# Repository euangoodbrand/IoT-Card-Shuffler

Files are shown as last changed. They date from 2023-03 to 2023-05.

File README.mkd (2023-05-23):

# Card Shuffler

<div style="text-align: center;">
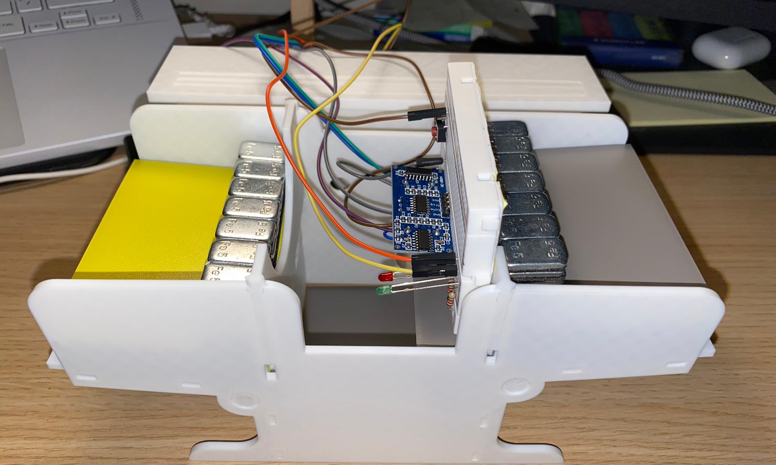
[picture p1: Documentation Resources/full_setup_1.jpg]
full_setup_1
  
</div>

This is the documentation for a Card Shuffler device, which is controlled over Wi-Fi using an aREST interface and has built-in jamming detection.

## Video Demonstration

Link: https://vimeo.com/829240523

Video below, click on image if video doesn't run (will redirect to vimeo where video is hosted)

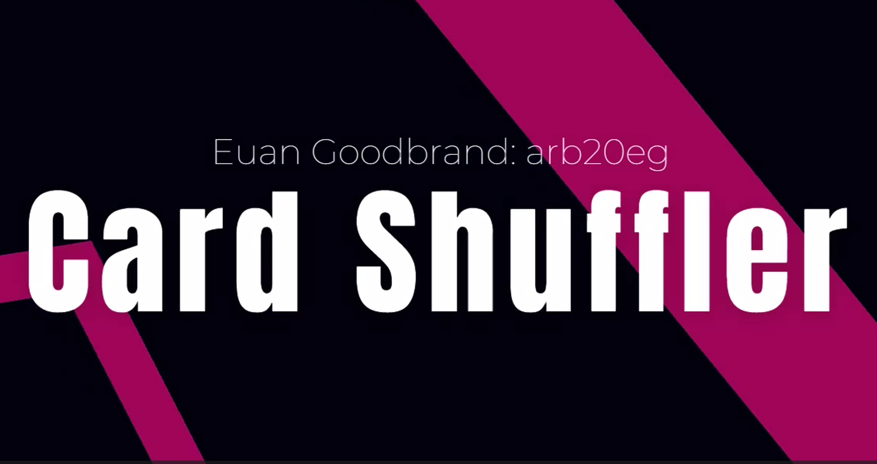
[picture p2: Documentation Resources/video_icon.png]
Video of Card Shuffler (https://vimeo.com/829240523)


## Software Design
The software is composed of two components, the aREST Interface and the Arduino code.

### aREST Interface Design
<div style="text-align: center;">
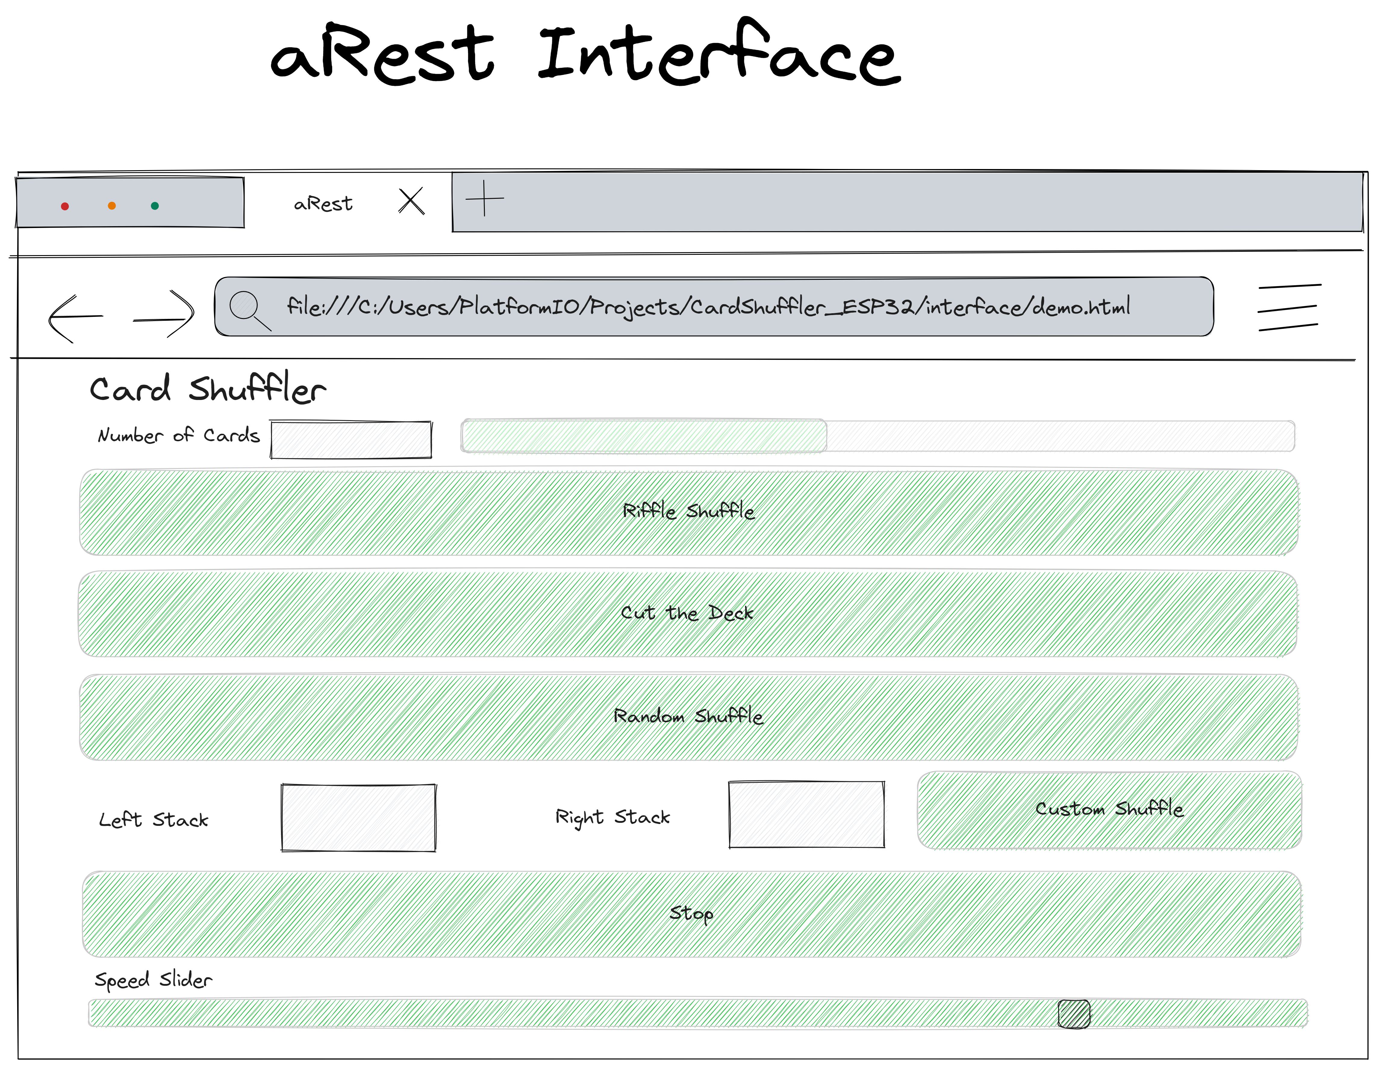
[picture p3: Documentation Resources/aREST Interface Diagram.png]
aREST Interface Design
  
</div>

The aREST interface must be easy to use and intuitive giving visual feedback to the user also. The design must also be simple and only include necessary features, no superfluous features should be on the interface and any features added should have a minimal design that is accessible. The interface was designed to have these features: Buttons for each shuffle (Riffle, Cut, Random and Custom) as well as a stop button. The user should have control over the device therefore, the user can choose the number of cards they wish to shuffle, control the speed of the shuffling via a slider and customise their own shuffle (custom shuffle). The slider was used to that the user doesn’t' enter a value outside of the motors capacity.

### Arduino code
<div style="text-align: center;">
  Software diagram
</div>
The code must be able to interact with the aREST interface as well as perform certain functions. As this is an IoT device it must firstly Connect to Wi-Fi via networking and be able to perform OTA firmware updates.
The code must also be able to control the  motors in the necessary ways to shuffle a Riffle-Shuffle, Cutting a deck, Random Shuffle and a Custom Shuffle whilst also taking into account the users selected number of cards and shuffling speed in any calculations.
The device also has an ultrasonic sensor, the code must stop all the motors whenever a distance below a certain threshold is detected which would be a card jam, the motors need to stop to ensure  no card damage is caused. Any necessary information should also be printed to the serial monitor or given to the user on the aREST interface. The code must also  incorporate a button to start Firmware updates and LEDs to inform the user of card jams detected.

## Hardware Design

The following components were used in the hardware design of the card shuffler project:

- Adafruit ESP32 Featherboard: The main microcontroller for this project, running the main logic and controlling the other hardware components. It's a powerful board with built-in Wi-Fi capabilities.

- Adafruit Motor Shield: This is used to control the DC motors which power the card shuffling mechanism. (Motor setup instructions were found here: https://gitlab.com/hamishcunningham/the-internet-of-things/-/blob/master/micasa/08-a-robocar.mkd)

- DC Motors: Two DC motors are used, which are controlled by the Motor Shield. These are responsible for the actual shuffling operation.

- Ultrasonic Sensor: An ultrasonic sensor is used to detect jams and stop the shuffler in case of issues.

- LEDs: Two LEDs are used to visually indicate the system status.

- Breadboard: Used for prototyping and connecting the various components.

These components are connected together along with the 3D printed chassis as shown in the relevant images in the connections section

### Hardware Connections

The following hardware connections are required for the code:

// HC-SR04 Sensor declarations
#define trigPin 17  // connected to A2_I34
#define echoPin 16  // connected to A1_DAC1
#define led 10      // some GPIO pin for LED1
#define led2 6      // some GPIO pin for LED2

// Create the motor shield object with the default I2C address
Adafruit_MotorShield AFMS = Adafruit_MotorShield(); 

// And connect 2 DC motors to port M3 & M4 !
Adafruit_DCMotor *L_MOTOR = AFMS.getMotor(4);
Adafruit_DCMotor *R_MOTOR = AFMS.getMotor(3);

Please make the following connections:

- Connect the `trigPin` of the HC-SR04 ultrasonic sensor to digital pin 17 of the microcontroller.
- Connect the `echoPin` of the HC-SR04 ultrasonic sensor to digital pin 16 of the microcontroller.
- Connect the `LED1` pin to digital pin 10 of the microcontroller.
- Connect the `LED2` pin to digital pin 6 of the microcontroller.

Additionally, the code utilizes the Adafruit Motor Shield library to control DC motors. Connect two DC motors to ports M3 and M4 of the Adafruit Motor Shield.

Note: Ensure that the motor shield is properly connected to the microcontroller and the necessary libraries are installed.

Finally, please refer to the hardware documentation or pinout diagrams of your specific microcontroller board and ensure the correct pin mappings for the `trigPin`, `echoPin`, `LED1`, and `LED2` connections.

**ESP32 and MotorDriver**

The ESP32 is connected to the Motordriver and the Motors in the following configuration. The setup also requires two batteries, abattery to power the motors and a lithium battery to allow the card shuffler to work without being plugged in.

<div style="text-align: center;">
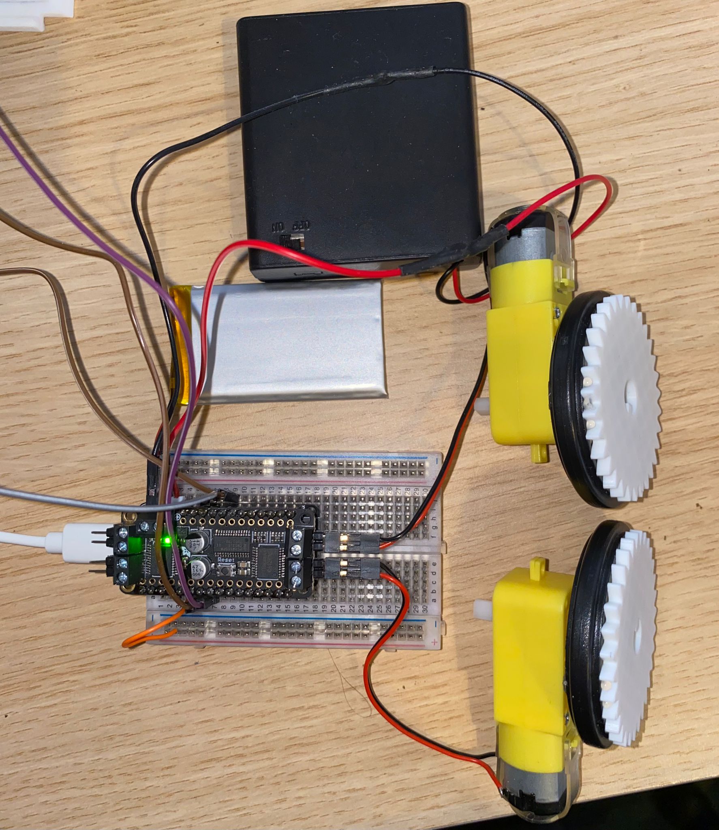
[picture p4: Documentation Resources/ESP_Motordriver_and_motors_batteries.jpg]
ESP_Motordriver_and_motors_batteries
  
</div>

**Ultrasonic Sensor**

The ultrasonic sensor is attatched to a seperate breadboard so that it can be mounted inside the chassis, this is to allow the ultrasonic sensor to be able to detect card james as well as give the user visuals of the LEDs attatched to that same breadboard. The button for OTA updates is also on this breadboard to allow the user to be able to press it easily for new firmware.

<div style="text-align: center;">
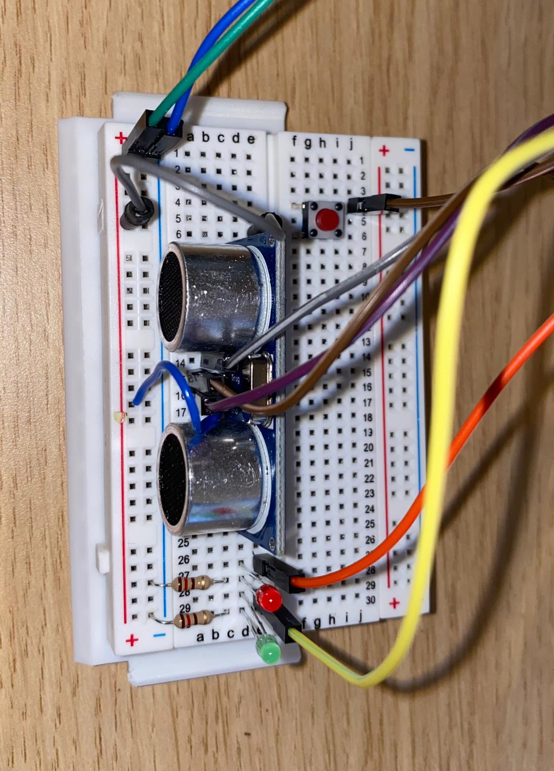
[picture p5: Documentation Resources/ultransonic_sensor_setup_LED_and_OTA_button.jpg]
ultransonic_sensor_setup_LED_and_OTA_button
  
</div>

The ultrasonic sensor breaboard can be easily mounted to the chassis using the sticky bottom of the breadboard as shown below:
<div style="text-align: center;">
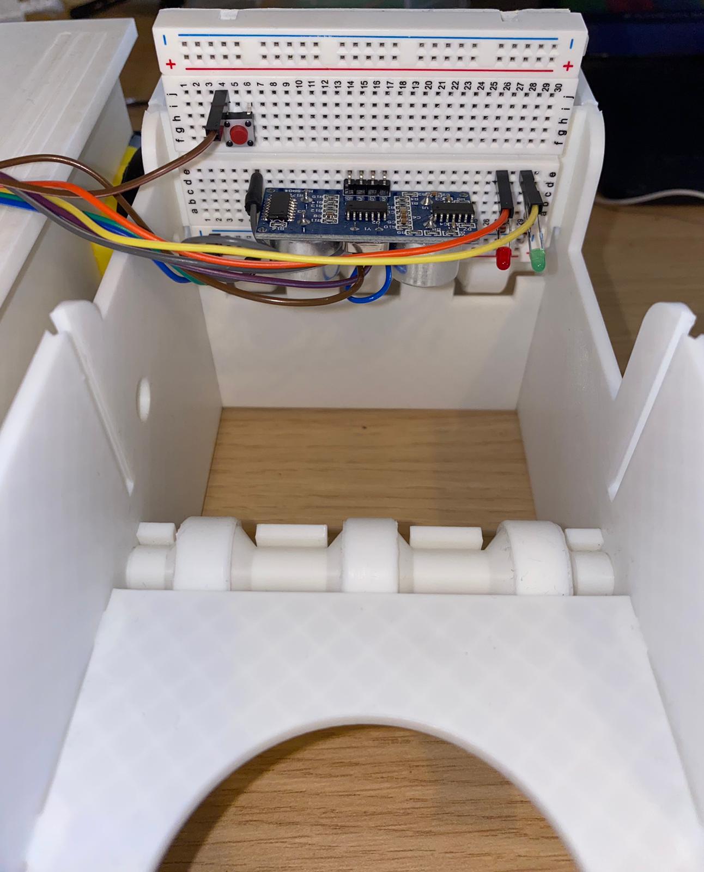
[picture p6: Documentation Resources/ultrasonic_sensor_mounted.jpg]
ultrasonic_sensor_mounted
  
</div>

## 3D Printed Chassis

The main structure of the card shuffler is a 3D printed chassis, designed to hold the cards and incorporate the mechanical parts needed for shuffling. The design should be simplistic and immediately obvious to the user how it functions such as where to put the cards. 

### Chassis Design
The components were designed using Fusion 360 software and printed using a P1P Bambu Labs 3D printer using Bambu Studio Slicer Software. All components were designed using measurements from a digital vernier callipers so that they have a high resolution of +- 0.05 mm. The 3D printer has a resolution of 0.1mm vertically and 0.4mm horizontally.

The design is made up of 15 different components:

**Sides**
The sides are the main component holding the design together, they allow the other components to connect in a secure way and hole the cards in from their sides. They include holes for the shaft to spin inside. These were printed on a smooth 3D printing bed so that the inside wall of the sides is smooth allowing the lowest friction for the cards.
<div style="text-align: center;">
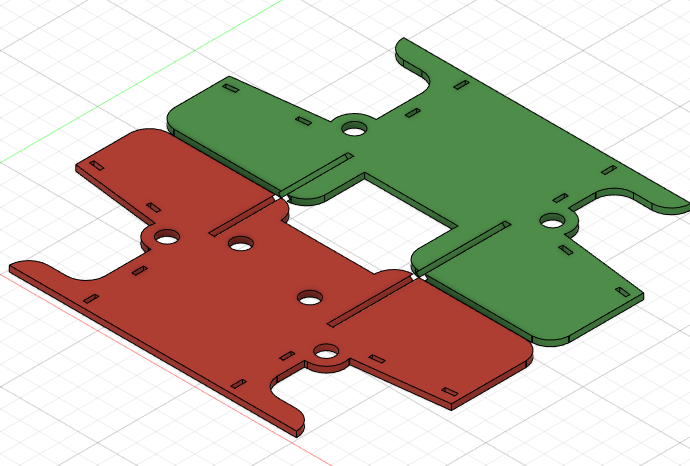
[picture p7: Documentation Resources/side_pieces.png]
side_pieces
  
</div>

**Spacers**
The spacers create horizontal structure in the shuffler and dictate the width of the cards put into the chassis. The current design allows for cards of 91 mm * 73mm and other similar smaller sized cards. Too small cards will not work. Two different designs of spacers were created for the two different shaft variants.
<div style="text-align: center;">
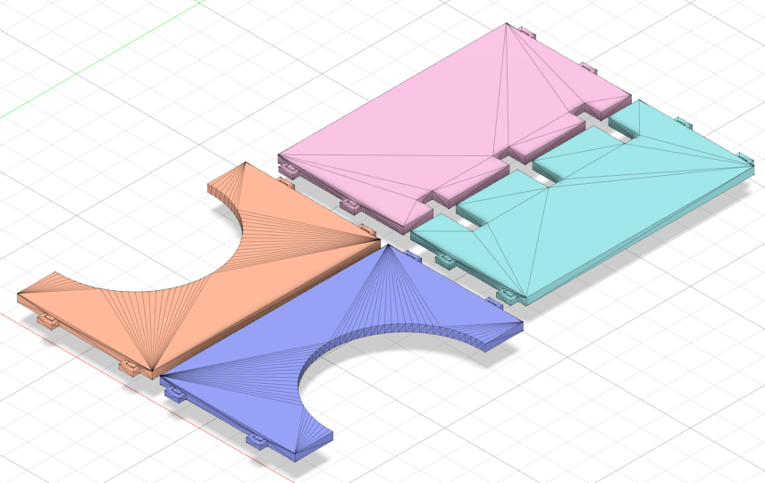
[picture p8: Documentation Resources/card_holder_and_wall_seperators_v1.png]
card_holder_and_wall_seperators_v1
  
</div>

**Card holders**
The card holders allow the cards to sit on top of them and slide off onto the motor shafts. They have a section removed to allow the easy removal and placing of cards as you are holding them. These pieces were also printed on a smooth 3D printing bed ass they make the most contact with the cards, this is to reduce friction. 
<div style="text-align: center;">
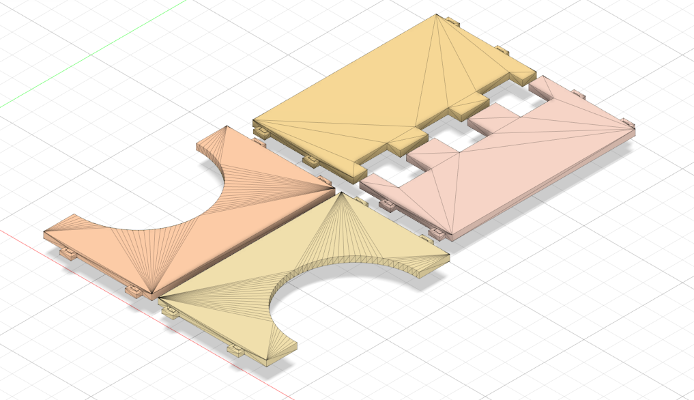
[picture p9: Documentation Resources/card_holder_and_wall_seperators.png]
card_holder_and_wall_seperators
  
</div>

**Card Blockers**
The card blocks are designs to be able to slide vertically on the side pieces, this allows the careful calibration of the blockers to only allow one card to be shuffler each time by the motors. Depending on the card thickness they ca be adjusted accordingly, this is useful for cases such as mine where I have cards in sleeves and sometimes even double sleeves that are of different thicknesses.
<div style="text-align: center;">
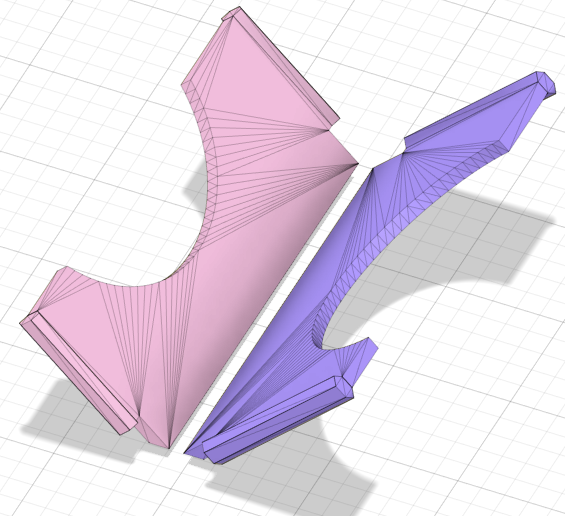
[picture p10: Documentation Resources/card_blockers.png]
card_blockers
  
</div>

**Motor Shaft**
There are two motor shaft designs v1 was found to be less effective than v2, both designs require the addition of rubber grips and are designed to hold specific rubber pieces, this is to ensure that the cards are pushed along by the motors as the plastic 3D printed is not enough to push the cards through. 

<div style="display: flex; justify-content: center;">
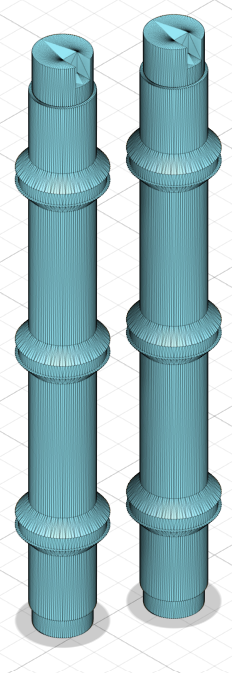
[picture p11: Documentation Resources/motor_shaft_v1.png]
motor_shaft_v1
  
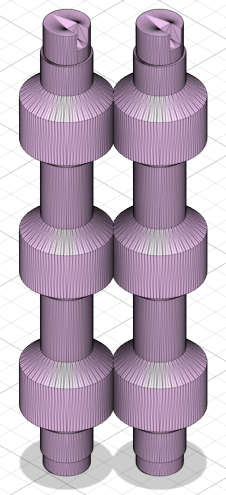
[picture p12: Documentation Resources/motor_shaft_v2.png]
motor_shaft_v2
  
</div>

The rubber bands are glued around the shaft like this:
<div style="text-align: center;">
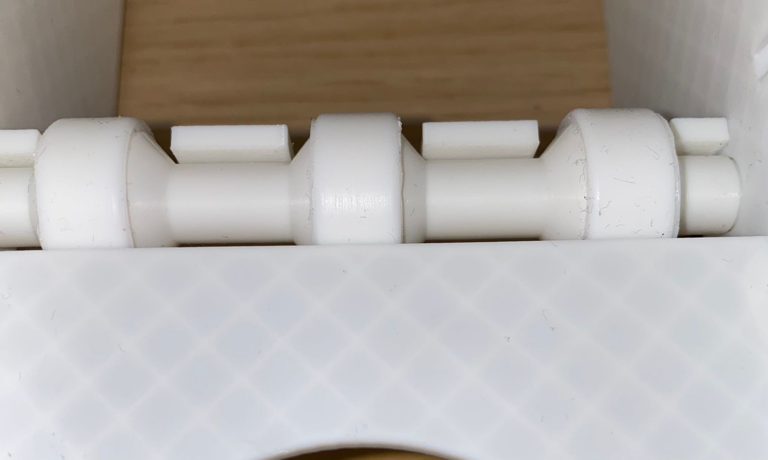
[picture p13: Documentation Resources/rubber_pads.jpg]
  
</div>

**Motor Holders**
These pieces are designed to house the motors securely, this is so that only the rotation force is applied to the shafts and not the motors or chassis themselves. This ensures the secure and steady rotation of the motors and allows the motors to run at full speed despite the wight of the cards and the top weights. This component is designed to use the small piece sticking out of the motors to securely fasten it inside.

<div style="text-align: center;">
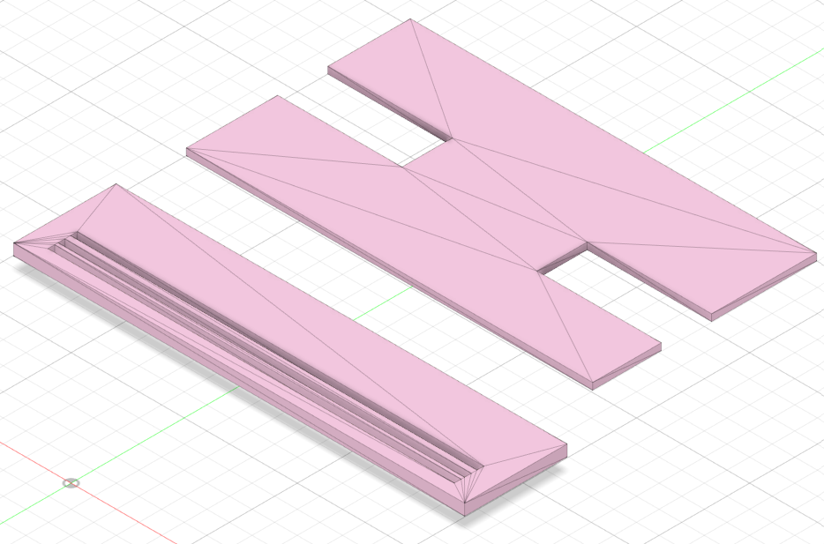
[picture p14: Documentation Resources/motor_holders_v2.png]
motor_holders_v2
  
</div>

### Assembly

The 3D Chassis is split into two main parts. The card shuffler and the Motor housing which are then connected via the gears. 

**Card Shuffler**

The card shuffler is made of 10 different 3D printed parts and is assembled like this:
<div style="text-align: center;">
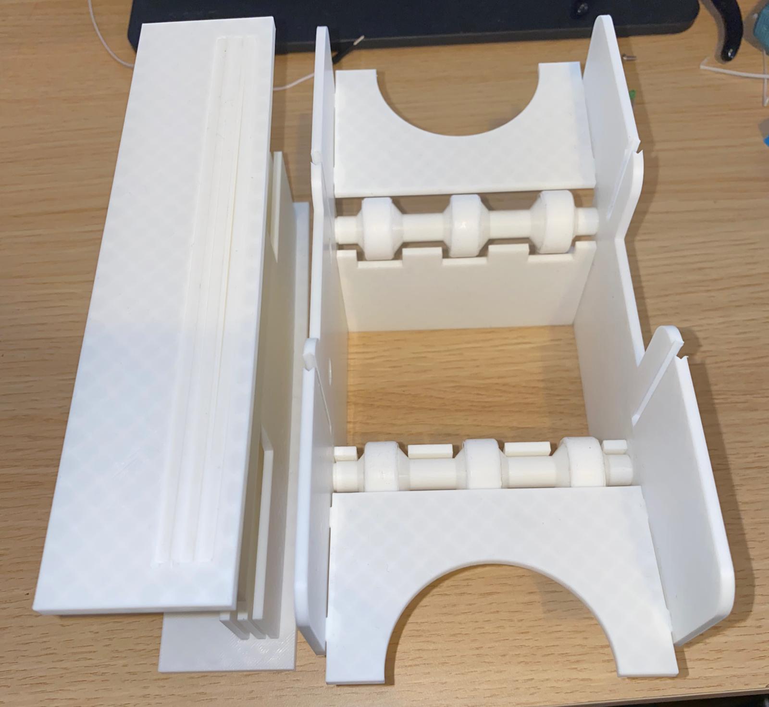
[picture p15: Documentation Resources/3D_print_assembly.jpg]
  
</div>

**Motor Housing**

The motor housing is composed of 4four 3D printed parts that are put together as so, there is a front and back to show how the motors are housed and how the gears are positioned on the front:

<div style="display: flex; justify-content: center;">
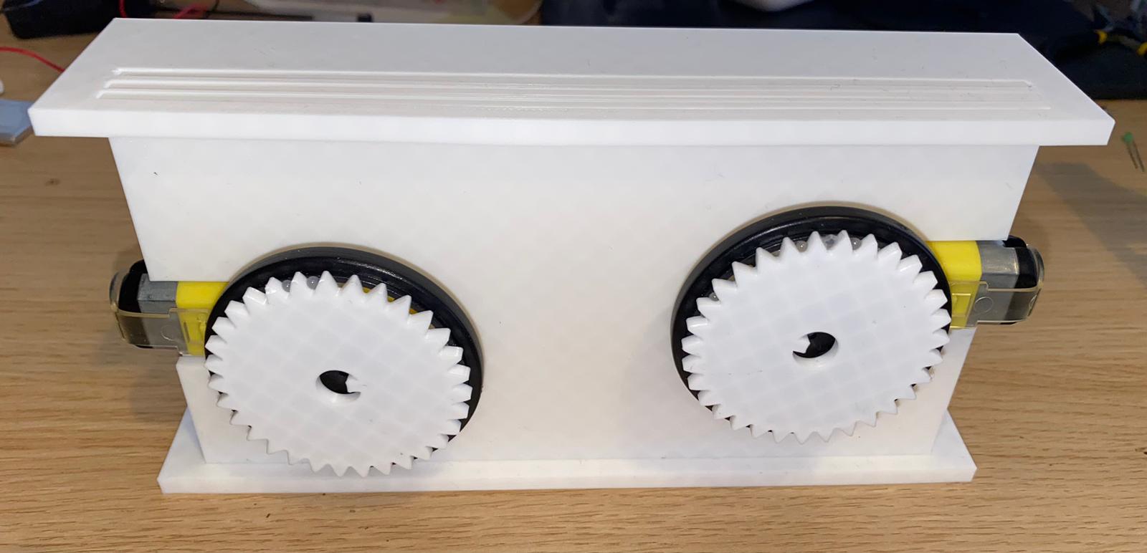
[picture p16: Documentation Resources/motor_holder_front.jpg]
MH Front
  
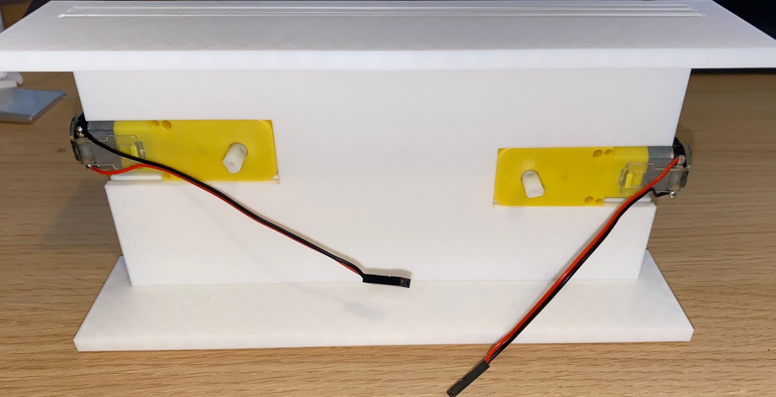
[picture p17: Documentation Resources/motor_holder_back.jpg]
MH back
  
</div>

## Libraries Used

This project uses several libraries to manage different aspects of the device's functionality. Here's a list of these libraries and their roles:

- `WiFi.h`: This library is used for managing Wi-Fi connections, allowing the device to connect to the internet. [More Information](https://github.com/espressif/arduino-esp32/tree/master/libraries/WiFi)

- `aREST.h`: This library is used for handling RESTful services, providing a simple way to interact with the device over HTTP. [More Information](https://github.com/marcoschwartz/aREST)

- `Wire.h`: This library is used for managing I2C communications, which are used for communicating with the motor shield. [More Information](https://www.arduino.cc/en/Reference/Wire)

- `Adafruit_MotorShield.h`: This library is used for controlling the Adafruit MotorShield, which is used for controlling the motors. [More Information](https://learn.adafruit.com/adafruit-motor-shield-v2-for-arduino/install-software)

- `HTTPClient.h`: This library is used for making HTTP requests. It's used in this project to check for and download firmware updates. [More Information](https://github.com/espressif/arduino-esp32/tree/master/libraries/HTTPClient)

- `Update.h`: This library is used for performing OTA updates. It's used to apply the firmware updates downloaded by HTTPClient. [More Information](https://github.com/espressif/arduino-esp32/tree/master/libraries/Update)

## Hardware requirements
- ESP32 Featherboard or other WiFi-enabled microcontroller
- Adafruit MotorShield Board
- HC-SR04 ultrasonic sensor
- Two DC motors
- Two LEDs (for jamming indication)
- Button for OTA Updates
- 3D Printed Case (Stl files can be found in Hardware Design Folder)
- Some cards to shuffle :) (specifically 93mm * 71mm)
- Jumper cables
- Rubber grips for the motor shafts
- Small weights for holding the cards flat

## Software
### Requirements
- Arduino IDE (or any compatible environment, e.g. vscode with platformio)
- Necessary libraries installed

**List of Libraries**
- [WiFi](https://www.arduino.cc/en/Reference/WiFi)
- [aREST by marcoschwartz](https://www.arduino.cc/reference/en/libraries/arest/)
- [Wire](https://www.arduino.cc/en/Reference/Wire)
- [Adafruit Motor Shield V2 Library by adafruit](https://www.arduino.cc/reference/en/libraries/adafruit-motor-shield-v2-library/)
- [Adafruit SPIFlash by adafruit](https://www.arduino.cc/reference/en/libraries/adafruit-spiflash/)
- [AsyncTCP by me-no-dev](https://github.com/me-no-dev/AsyncTCP)
- [ESP Async WebServer by me-no-dev](https://github.com/me-no-dev/ESPAsyncWebServer)
- [Adafruit BusIO](https://www.arduino.cc/reference/en/libraries/adafruit-busio/)
- [SPI](https://www.arduino.cc/en/Reference/SPI)
- [Adafruit ImageReader Library](https://www.arduino.cc/reference/en/libraries/adafruit-imagereader-library/)
- [Adafruit Unified Sensor](https://www.arduino.cc/reference/en/libraries/adafruit-unified-sensor/)
- [DNSServer](https://www.arduino.cc/en/Reference/DNSServer)
- [ESPmDNS](https://www.arduino.cc/en/Reference/ESPmDNS)
- [FS](https://www.arduino.cc/en/Reference/FS)
- [HTTPClient](https://www.arduino.cc/en/Reference/HTTPClient)
- [arduino-lmic by hamishcunningham](https://github.com/hamishcunningham/arduino-lmic)
- [Preferences](https://www.arduino.cc/en/Reference/Preferences)
- [Update](https://www.arduino.cc/en/Reference/Update)
- [WebServer](https://www.arduino.cc/en/Reference/WebServer)
- [WiFiClientSecure](https://www.arduino.cc/en/Reference/WiFiClientSecure)

### Constants
The following constants are defined, use them wisely:
-  `FIRMWARE_VERSION`: Current firmware version of the device.
-  `FIRMWARE_SERVER_IP_ADDR`: IP address of the firmware server.
-  `FIRMWARE_SERVER_PORT`: Port number of the firmware server.
-  `apSSID`: SSID for the ESP32's access point.
-  `apPassword`: Password for the ESP32's access point (and no, "password123" is not a good choice ~~ignore my password~~).

## Setup and Usage
- You can control the motors by sending requests to the following REST endpoints:
  - `/stop`
  - `/oppositeConstant`
  - `/alternating`
  - `/randomMotion`
  - `/customSuhffle`
  - The device uses an ultrasonic sensor to detect card jams. If a jam is detected, it stops the motors and turns on the red LED.

## Provisioning Instructions:
<div>
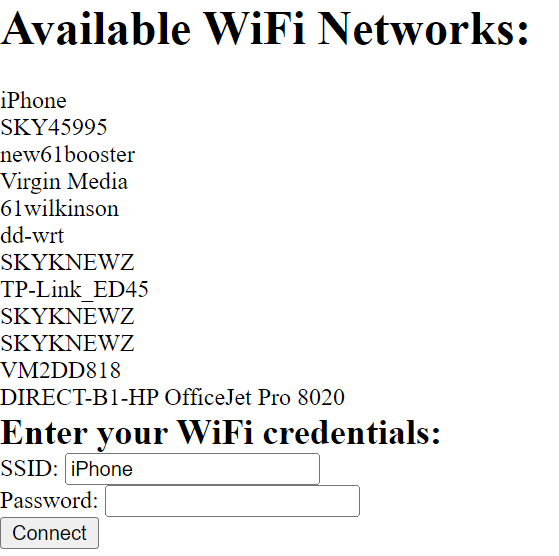
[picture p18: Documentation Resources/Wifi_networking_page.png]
Wifi_networking_page
  
</div>

The Card Shuffler also has provisioning capability allowing connection to any Wifi and easy setup.

These instructions will guide you through the process of provisioning your ESP device, so that it can connect to your Wi-Fi network and become accessible via its own access point.
1.  **Put the ESP into bootloader mode:**
 - Hold down the "boot" button on the ESP board, then press the "reset" button.
 - Release the "reset" button, then release the "boot" button.
2.  **Burn the code onto the ESP:**
 - Use your preferred method to burn the code onto the ESP board.
3.  **Connect to your computer and select the relevant port:**
 - Connect your ESP board to your computer via USB.
 - Select the relevant port in your programming software.
 - Press the "reset" button to run the code.
4.  **Connect to the access point created by the ESP:**
 - The ESP will create its own access point, which you can connect to.
 - Define a name and password for the access point.
5.  **View the website from the ESP:**
 - In a web browser, go to the URL http://192.168.4.1 to view the website hosted by the ESP.
6.  **Enter your Wi-Fi credentials:**
 - Type in the Wi-Fi credentials that you want the ESP to connect to.
 - Make sure that your firewall is not blocking this connection.

## OTA Update and Instructions:
- The code includes an Over-The-Air (OTA) update mechanism. The device checks for updates from a specified server at startup and applies them if found.

These instructions will guide you through the process of updating your ESP device over the air (OTA), using a Python server and compiled binary files.
1.  **Ensure that your computer and ESP are on the same Wi-Fi network:**
 - Connect your computer and ESP to the same Wi-Fi network.
 - You can use a hotspot if you prefer.
2.  **Find the IPv4 address of your computer's wireless LAN:**
 - Open a new terminal and type "ipconfig".
 - Look for the IPv4 address under the "Wireless LAN" section.
3.  **Start a Python server:**
 - Open another terminal window and type "python -m http.server 8000".
 - This will start a server that listens on port 8000.
4.  **Upload the sketch.ino file:**
 - Use your preferred method to upload the sketch.ino file to your ESP board.
5.  **Increment the firmware version:**
 - Go to "Sketch" > "Export compiled binary" in your programming software.
 - Save the binary file as "N.bin", where "N" is the version number you are updating to.
 - Increment the version number in your sketch.
6.  **Save the binary file to the Python server directory:**
 - Save the binary file to the directory where you ran the Python server (step 3).
 - Save it as "N.bin", where "N" is the version number you are updating to.
7.  **Add a version.txt file:**
 - Create a file called "version.txt" in the same directory as the binary file.
 - Inside the file, add the integer version number that you are updating to.
8.  **Reset the ESP board and open the serial monitor:**
 - Reset the ESP board by pressing the "reset" button.
 - Open the serial monitor in your programming software and select the correct port.
9.  **Wait for the update to complete:**
 - Press the button on the breadboard to start the updating process.
 - The ESP board will connect to the Python server and download the new firmware.
 - Wait for the update to complete.

## Testing

### Sensor Testing
The sensor was tested at various distances measured with a calliper and these expected distances were compared to the actual read distances from the sensor, this showed that the sensor outputted results to the nearest cm. This changed the design direction as originally I has intended to use the ultrasonic sensor for both detecting card jams and measuring the height if the stack of cards to determine when to stop shuffling when enough cards were in the stack, however as cards are much thinner than 1cm this couldn't be done. In the end only card jamming detection could be done with the hardware at the resolution.

<div style="text-align: center;">
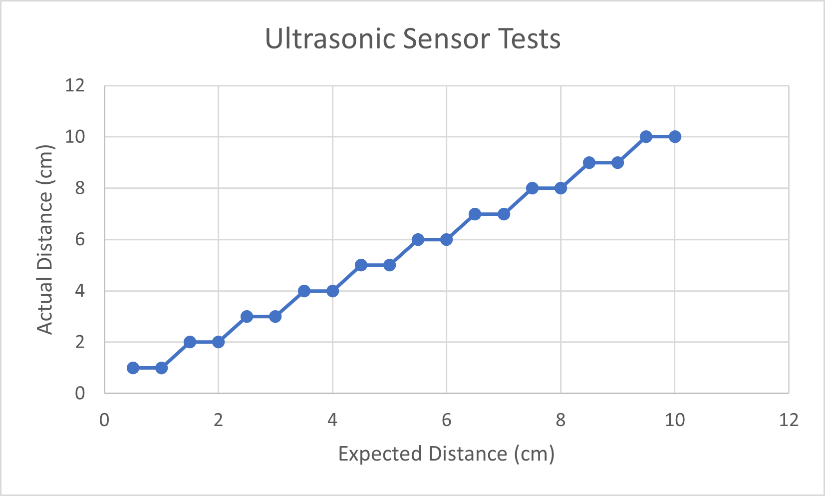
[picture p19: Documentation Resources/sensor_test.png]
sensor_test
  
</div>

### Motor Timing Testing for number of Cards Shuffled
Testing and calibration was done on the  motor timings. It was found that the amount of cards being shuffled was much higher than expected to the point the motors would continue running even after the maximum amount of cards the chassis could hold had already been shuffled. This called for proper testing and calibration.
It was found that the amount of cards shuffled was around 5 times as much as expected as shown in the table above, therefore, the code was altered to reduce the motor running duration by a scale of 5. The below table is the resulting number of cards shuffled based off the number inputted and the test was done twice to confirm. This shows that the card shuffler can shuffle the correct amount of cards pretty close to the expected number, further calibration could get the accuracy correct every time but this would require a much longer calibration process to approach  the correct calibrated values which could be done in potential further work.
<div style="display: flex; justify-content: center;">
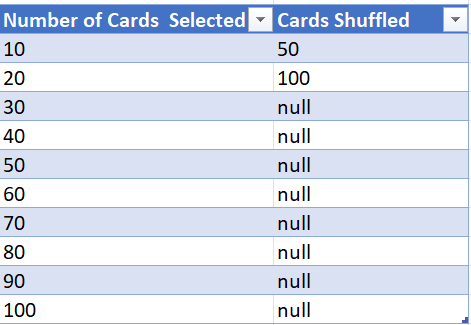
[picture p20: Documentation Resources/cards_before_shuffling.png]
cards_before_shuffling
  
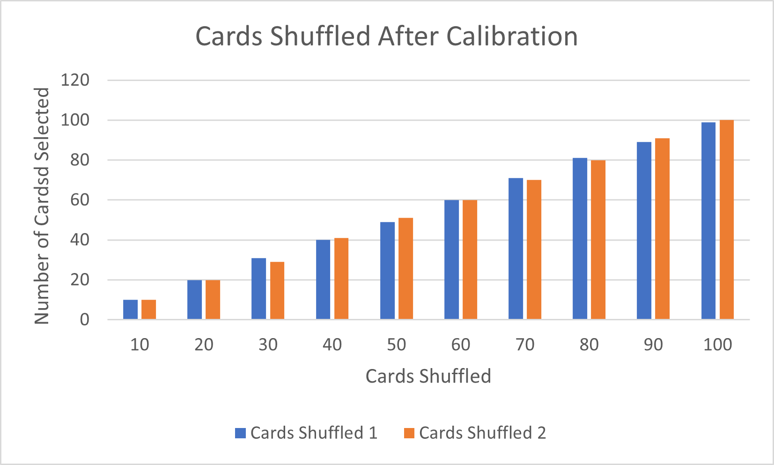
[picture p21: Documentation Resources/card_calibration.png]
card_calibration
  
</div>

### 3D Printed chassis testing and Iterative Design Process
Before the motors were added to the design or the motor holders were even designed various testing has been done to ensure the chassis could shuffle cards before going forward with the electronic or software design and implementation. 
Multiple iterations of the chassis were made and tested with slow improvements.
The first iteration was printed at too low a quality and needed to be printed again using a higher resolution, the lower quality caused connections to not fit correctly and the shafts to grind as I cranked them which proved difficult meaning that the motors wouldn’t be able to spin them. 

<div style="text-align: center;">
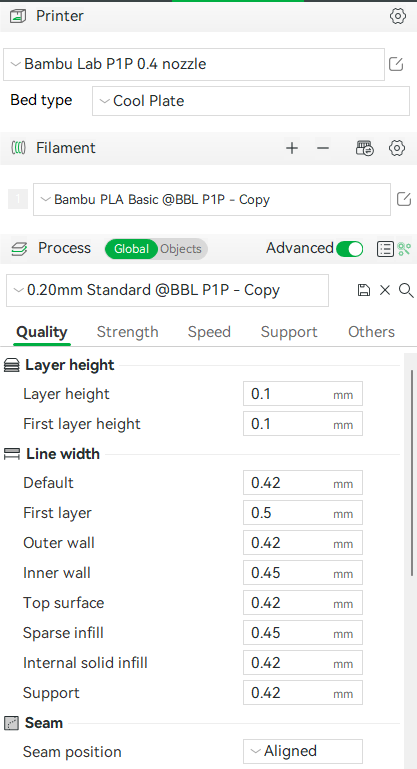
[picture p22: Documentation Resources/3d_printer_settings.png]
3d_printer_settings
  
</div>

After a reprint at 0.1mm layer height there were other issues, due to the 3D printed bed temperature being too low the PLA material warped heavily causing the chassis to not fit together correctly and not sit flat on any surfaces.
I increased the temperature of the hot bed to 55 degrees Celsius and the chassis now fit together correctly and the shafters rotated relatively smoothly, however I noticed the texture of the shafts was rougher than I expected, this was due to 3D printing the shafts horizontally and not vertically meaning the shafters were essentially made of many square cross sections rather than circular ones which is  not good for rotating parts. After reprinting these correctly the chassis worked and the shafts spun smoothly.
The process was not finished though as the cards did not make contact with the shaft by a few mm,  even adding rubber grips didn't allow the cards to touch. Therefore, I redesigned new shafts and new spacers to house them. This meant the shaft was thicker and now made contact with the cards when rubber grips were added. 
The device was now capable of shuffling but there was some holdups due to friction between the chassis and the cards. This was because the hot bed that my 3D printer came with was a textured bed meaning it applied a rough texture to all my 3D prints, this is normally good to break up the lines produced by a 3d printer but for parts requiring low friction this was an issue. 
I researched compatible smooth hot beds and purchased one, after it arrived I reprinted the parts that made contact with the cards or shafts and had these areas face down on the printer bed so they adopted the smooth face, this also meant I had to buy a flat tool to help remove them as no texture made the 3D prints adhere to the bed.
Finally, the last problem was the cards bending. Not all cards were able to stay perfectly flat and therefore, would not go under the card blocker and through the slot. This meant that weights like the ones in the image below were needed to apply constant downwards pressure. This also helped by adding extra downforce getting extra grip with the rubber.
After this the cards printed very well and smoothly and the chassis design was complete.

<div style="text-align: center;">
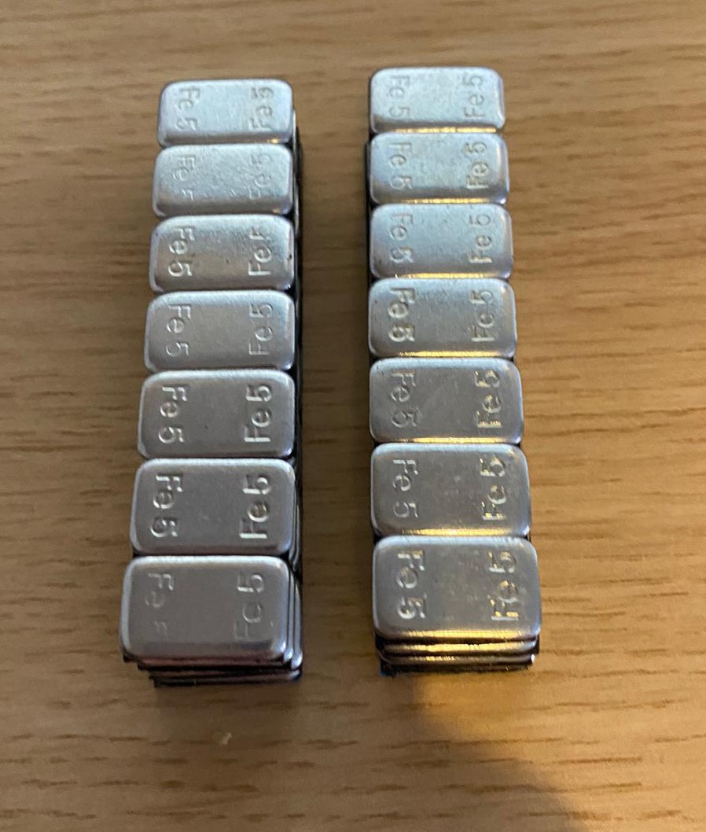
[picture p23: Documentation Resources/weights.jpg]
  
</div>

### Unit Testing Arduino Code
Unit testing was attempted but there are no standard built-in unit testing frameworks in C++ for Arduino (like JUnit for Java or unittest for Python). This code does not lend itself easily to unit testing, as it's largely dependent on hardware interactions and also on the aREST library. Also, the code would need to be largely refactored to allow for unit testing by abstracting the functions which would require  larger time frame than the project allows, and it would likely not be worth it due to most of the testing being reliant on hardware which unit tests cannot account for.

### Acceptance Testing
Acceptance testing seems to be the most appropriate type of testing for this project given the different components and the time allowed. 

**Acceptance Criteria:**
- The different shuffles must shuffle as expected.
- The card counter should output the expected number of cards.
- The progress bar should start when the cards start shuffling and finish at the same time the shuffling is over.
- The card counter should always show the correct value for cards shuffled.
- The ultrasonic sensor should correctly identify card jams.
- The cards should not be damaged.
- The user should be able to select the number of cards to shuffle.
- The user should be able to select the speed of the shuffler.
- The interface feedback (progress bar and cad counter) should reset for each new shuffle.

The project has been tested from the perspective of the user as a whole to ensure that it meets the specifications that the user would expect. Each shuffle type has been tested with different numbers of cards and at different speeds. The results were that the shuffle types shuffled as expected, outputted the correct number of times even at different speeds and the progress bar and card counter were accurate in their timings and for the amount of cards shuffled throughout the process. the ultrasonic sensor correctly identified card jams and stops the motors as well as the stop button stopping the motors when pressed. The interface correctly resets when a new shuffle is performed.

### Overall Testing
|Test No.|Description|Expected Result|Actual Result|Successful Implementation?|
|:----|:----|:----|:----|:----|
|1|Test WiFi connectivity: Verify device can connect to WiFi network|Connection should be successful and stable|Connection was successful and stable|Yes|
|1.1|Test different WiFi networks: Verify device can connect to multiple networks with varying security protocols (WEP, WPA2, WPA3, etc.)|The device should be able to connect to all supported types of networks|Device successfully connected to all tested networks|Yes|
|1.2|Test WiFi signal strength: Verify device can connect to WiFi network from different distances|Device should maintain stable connection within the specified range|Stable connection was maintained within the specified range|Yes|
|1.3|Test WiFi auto-reconnect: Verify that the device reconnects to the network after losing connectivity|Device should reconnect after the network is restored|Device reconnected after pressing the reset button|Yes|
|2|Test OTA update functionality: Check if device can receive, process, and install updates via WiFi|Firmware update should occur without error|Firmware update was successful|Yes|
|2.1|Test OTA update integrity: Check if updates install correctly without data corruption|The update should install and the system should work as intended after the update|Update installed correctly and system worked as intended|Yes|
|2.2|Test OTA update roll-back: Verify if the device can revert to previous firmware version in case of an unsuccessful update|Device should be able to revert to previous firmware version if an update fails|Device reverted to previous firmware version after naming the old firmware as a new version|Yes|
|3|Test Ultrasonic Sensor functionality: Verify sensor can measure and report accurate distances|Correct distance should be returned|Correct distance was returned|Yes|
|4|Test Motor operation: Verify motors can run smoothly without errors|Motors should run without error|Motors ran without error|Yes|
|5|Test stop() function: Verify that both motors stop when the function is called|Both motors should stop|Both motors stopped as expected|Yes|
|6|Test oppositeConstant() function: Verify that motors can run in opposite directions when the function is called|Motors should run in opposite directions|Motors ran in opposite directions as expected|Yes|
|7|Test alternating() function: Verify that motors can run alternately when the function is called|Motors should run alternately|Motors ran alternately as expected|Yes|
|8|Test randomMotion() function: Verify that motors can run in random motions when the function is called|Motors should run in random motion|Motors ran in random motion as expected|Yes|
|9|Test customShuffle() function: Verify that cards can be shuffled in a custom manner when the function is called|Cards should be shuffled customly|Cards were shuffled in a custom manner as expected|Yes|
|10|Test the interface's connection with the device: Verify the UI can successfully interact with the device|Successful interaction with the device|Interaction with the device was successful|Yes|
|11|Test shufflingSpeed adjustment on the interface: Verify that changes made on the interface reflect in the shuffling speed|Shuffling speed should change correctly|Shuffling speed changed correctly|Yes|
|12|Test the 'oppositeConstant' button on the interface: Verify that pressing the button shuffles cards in an opposite constant manner|Cards should be shuffled in opposite constant manner|Cards were shuffled in opposite constant manner|Yes|
|13|Test the 'alternating' button on the interface: Verify that pressing the button shuffles cards in an alternating manner|Cards should be shuffled in alternating manner|Cards were shuffled in alternating manner|Yes|
|14|Test the 'randomMotion' button on the interface: Verify that pressing the button shuffles cards in a random motion|Cards should be shuffled in random motion|Cards were shuffled in random motion|Yes|
|15|Test the progress bar and card count on the interface: Verify that the UI displays the correct progress and card count|Should display progress and count correctly|Progress and count were displayed correctly|Yes|
|16|Test the OTA update notification: Verify that the device provides an alert or notification when an OTA update is available|The device should provide a timely notification when an OTA update is available|A timely notification was provided when an OTA update was available|Yes|
|17|Test Ultrasonic Sensor calibration: Verify if the sensor can be properly calibrated for accurate distance measurement|The sensor should be correctly calibrated and provide accurate distance readings|Sensor was correctly calibrated and provided accurate readings|Yes|
|18|Test if motors can resume after stop(): Verify if the motors can resume operation after the stop() function is called|Motors should resume operation without error|Motors resumed operation without error|Yes|
|19|Test the responsiveness of the interface: Verify the interface reacts promptly to user interactions|The interface should respond quickly to all user interactions|The interface responded quickly to all user interactions|Yes|
|20|Test the speed control of the motors: Verify if the speed of the motors can be controlled effectively|The speed of the motors should change correctly as per control inputs|The speed of the motors changed correctly as per control inputs|Yes|
|21|Test card counting accuracy: Verify the device correctly counts the number of cards shuffled|The device should provide a correct count of cards shuffled|The device provided a correct count of cards shuffled|Yes|
|22|Test the system's ability to handle different card types: Verify the device can handle different types of cards (e.g., plastic, paper, different sizes)|The device should be able to handle all supported card types effectively| The device could handle call standard card sizes below the size of 91mm * 71mm|Yes|

## Self-Assessment

Reflecting on this project, there are several areas where improvements can be made in future iterations and other projects.

### Workspace Environment
Maintaining a well-organized and properly equipped workspace is essential for efficiency and safety. For instance, filing parts of my 3D prints caused my mousepad to be frayed which is whatt I was building the project. This was my favourite mousepad so it's a shame, the lesson learnt is to have a proper setup when dealing with a project of this nature.

### Hardware Understanding
Greater knowledge and understanding of the hardware used in the project can lead to better design decisions and problem-solving. An instance from this project was a motor getting blown during testing. This could have been avoided with more comprehensive understanding of the motor's power requirements and operating conditions. In the future, I will look into hardware specifications further as well as their operating principles before integrating them into the design.

### Documentation
Good documentation practices are crucial not only for project management but also for troubleshooting and further development. During the course of this project, it was noticed that better documentation during the development phase, rather than close to the end, would have saved time and confusion. An example was not remembering which pin was assigned to which motor upon reassembly causing lots of wasted time. Going forward, regular updates to the documentation during the development phase will be implemented, detailing decisions, changes, and important specifications. 

### More research

More research could have gone into other similar designs that already exist. If more research was done then maybe it would have required less iterations to get to a working solution. Below is an image of the 3D parts printed that didn't end up in the final design due to different problems.

<div style="text-align: center;">
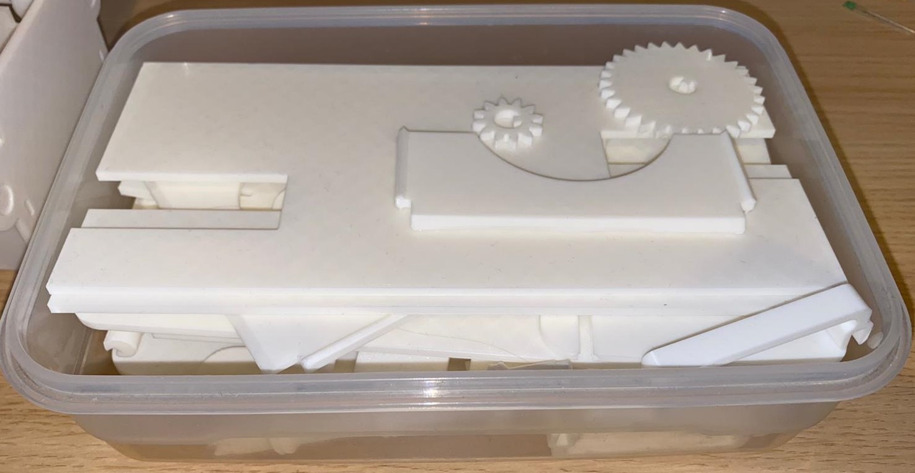
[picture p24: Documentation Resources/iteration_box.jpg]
iteration_box
  
</div>

### Future Improvements

**Adjustable Card Guide**
In future iterations of this project, implementing an adjustable card guide could be a useful feature. This mechanism, similar to the adjustable paper trays found in printers, would allow the shuffler to accommodate various sizes of cards. It would involve creating a movable guide within the card holder to securely position cards of different widths and lengths. This feature would increase the versatility of the card shuffler, allowing it to be used with a wider range of card games and deck styles.

**Improved Card Retrieval Mechanism**
Presently, accessing shuffled cards can be a bit challenging. For future iterations, an improved card retrieval mechanism could be designed. This could be a chute that guides the shuffled cards to a specific location or a platform where the shuffled cards are collected for easy pickup. 

**Enhanced Shuffling Mechanism**
The current shuffling mechanism moves the bottom card from one of two piles. While this does shuffle the cards randomly, it does not allow for all possible card permeations. Future versions could look at incorporating a more advanced shuffling algorithm or mechanism. This could include random selection of cards from different positions within the pile.

**User Interface**
The user interface of this project is simple and functional, but there is room for enhancement. Currently, the user interface only allows for changing the number of cards, shuffling speed and different shuffling methods adding the abililty to adjust settings for the card guide or other features could prove useful.

**Connectivity and IoT Security**
The current project utilizes aREST.js for network connectivity, which, while functional, presents certain limitations particularly concerning security. Future iterations would benefit from exploring alternative IoT platforms that provide enhanced security features such as AWS IoT or Google Cloud IoT.

**Smartphone Integration**
Integrating the card shuffler with a smartphone application could provide additional functionality and convenience. The smartphone app could allow users to control and monitor the shuffling process remotely, adjust settings, and receive notifications or alerts. This would enhance the user experience and provide more flexibility in using the card shuffler.

### What went well?

**Meeting Project Specifications**
Overall, the project successfully met its specifications, resulting in the creation of a functional card shuffling IoT device. The device is capable of shuffling cards, detecting card jams, and providing a user interface for control and monitoring.

**Sturdy Chassis Design**
The chassis of the device has a sturdy build and remains in excellent condition even after extensive testing. The 3D printed nature of the design allows for easy maintainability, scalability, and upgrades. Parts can be easily replaced or modified, providing flexibility for future improvements or alterations to accommodate different card sizes or design preferences.

**Functional User Interface**
The user interface of the device is simple and functional. Users can control the number of cards to shuffle, adjust the shuffling speed, and choose different shuffling methods. The implementation of REST calls and WiFi connectivity provides a convenient way to interact with the device remotely.

**Ease of Documentation Updates**
During the project, the importance of documentation became evident. Although there were some improvements to be made in the documentation process, updating the documentation as the project progressed was relatively easy due to the use of Markdown format. This allowed for clear and organized documentation, facilitating future development, troubleshooting, and sharing of the project.

**Time Management and Progress**
The project benefited from good time management practices, ensuring consistent and steady progress. The order in which tasks were completed was well-planned and logical, allowing for efficient development and troubleshooting. Regular tracking of progress and adherence to timelines helped maintain momentum and deliver the project within the expected timeframe.

**Testing and Debugging**
Thorough testing and debugging played a crucial role in the success of the project. Testing was conducted at various stages to ensure the functionality and reliability of the device. Issues and bugs were identified and addressed promptly, resulting in a stable final product. However, further improvements could be made in expanding the test coverage and implementing automated testing procedures.

**Learning and Skill Development**
The project provided valuable opportunities for learning and skill development. Through hands-on implementation, I gained practical experience in various aspects of hardware integration, software development, and IoT connectivity as well as some other skills such as using Fusion 360 and CAD design.

## Additional Resources and References

Below are some important resources and references that will provide further understanding and context to the project:

1. **Arduino Programming Language (API)**: This is the main reference to understand the Arduino Programming Language used to program the microcontroller in this project. You can find it [here](https://www.arduino.cc/reference/en/).

2. **WiFi.h**: This library provides the necessary functions to connect to Wi-Fi networks and set up an access point. Check out the source [here](https://github.com/espressif/arduino-esp32/tree/master/libraries/WiFi). Course notes on WiFI based provisioning: https://iot.unphone.net/#wifi-based-provisioning

3. **WebServer.h**: This library is used to create a simple HTTP server on the ESP32. View the source [here](https://github.com/espressif/arduino-esp32/tree/master/libraries/WebServer).

4. **HTTPClient.h**: This library provides functions to make HTTP requests, used to get firmware updates from the server. The source is available [here](https://github.com/espressif/arduino-esp32/tree/master/libraries/HTTPClient).

5. **Update.h**: This library is used for handling OTA updates on the ESP32. You can check out the source [here](https://github.com/espressif/arduino-esp32/tree/master/libraries/Update).

6. **Adafruit Motor Shield Library Documentation**: This [documentation](https://learn.adafruit.com/adafruit-motor-shield-v2-for-arduino/install-software) provides essential information about the motor shield library used in the project.

7. **Adafruit HUZZAH32 – ESP32 Feather Board**: This is the datasheet for the Adafruit HUZZAH32 – ESP32 Feather Board. It is available [here](https://learn.adafruit.com/adafruit-huzzah32-esp32-feather).

8. **aREST Library**: Here is the [aREST library](https://arest.io/) that makes building IoT devices easier.

9. **Arduino OTA Updates**: Check out this [tutorial](https://randomnerdtutorials.com/esp32-over-the-air-ota-programming/) to understand more about OTA updates in Arduino. Course notes on OTA updates: https://iot.unphone.net/#over-the-air-updates-ota

10. **Motor Setup**: https://gitlab.com/hamishcunningham/the-internet-of-things/-/blob/master/micasa/08-a-robocar.mkd  and https://iot.unphone.net/#a-simple-robot-car

11. **Ultrasonic Sensor HC-SR04 Setup Instructions** found here: https://gitlab.com/hamishcunningham/the-internet-of-things/-/blob/master/micasa/08-ultrasonicsensors.mkd and https://iot.unphone.net/#ultrasonic-sensors

12. **ESP32 S3**: Programming guide: https://docs.espressif.com/projects/esp-idf/en/latest/esp32s3/get-started/index.html and course notes: https://iot.unphone.net/#esp-idf-freertos-and-the-esp32-arduino-core

## Contact
- You can reach me at [egoodbrand1@sheffield.ac.uk](mailto:egoodbrand1@sheffield.ac.uk) for any queries.

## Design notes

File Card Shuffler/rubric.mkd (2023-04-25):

# Lab Assessment 2 (LA2, project) ###########################################

Design, build, test and document an IoT device that:

- demonstrates the typical IoT configuration of microcontroller, sensors and
  actuators (and, optionally, cloud-based analytics, data aggregation or
  control)
- is well-documented at both technical and operational levels, including
  hardware photographs, and a brief video (**maximum** 1 minute long) of the
  system in use

The system should exhibit a useful task of your choice, within the constraints
of the available hardware (an unPhone, or a TTGO watch, or a bare ESP32
feather, or the voice control "DIY Alexa" components, or etc. by arrangement).

The code and documentation of the device **must be located** in your gitlab
repository (`com3505-student-2023`) under a top-level directory named `LA2`.
Documentation must be in a `README.mkd` in the `LA2` directory, and code in a
subdirectory called `ProjectThing`. For example, when cloned the file
structure will look like this:

- `com3505-student-2023/LA2`
- `com3505-student-2023/LA2/README.mkd`
- `com3505-student-2023/LA2/rubric.mkd` (this file)
- `com3505-student-2023/LA2/`...other doc files etc....
- `com3505-student-2023/LA2/ProjectThing`
- `com3505-student-2023/LA2/ProjectThing/ProjectThing.ino`
- `com3505-student-2023/LA2/ProjectThing/`...other code files etc....
- ...etc....

The project is yours to keep after the course (and may serve as a
cyber-physical demonstration of your skills and interests for interviews and
the like).

The work will be assessed according to:

- hardware
- firmware code
- documentation

The assessment is **open-ended**, **qualitative**, and used to determine your
final classification for the course (pass, 3rd, upper or lower 2nd, 1st).

**Notes**:

- **Deadline**. Friday 19th May at 12 midday UK time. (At this point a
  snapshot of your gitlab repository will be taken for marking.)
- **Size**. If you have spent the approximate amount of time we recommend for
  a 10 credit course (around 8 hours per week) on the work so far, you should
  be able to achieve a good solution (including hardware, code and
  documentation) within a similar amount of time (8 hours per week of the
  project duration), or less.
- **Marks**. The assessment is marked out of 100 and contributes a possible
  maximum of 60 to your score for the course. Marks will be allocated for both
  qualitative and quantitative characteristics of hardware, code, and
  documentation. (LA1 and the exam are pass/fail threshold elements of your
  assessment; LA2 dictates your grade after passing the other two. It is
  possible to pass the course without completing LA2, in which case your mark
  will be 40.)
- **Design**. Have you chosen a task which: demonstrates the capabilities of
  IoT devices? is viable and realistic? Have you documented: the rationale for
  this task? how it will be implemented? and tested?
- **Code**. Code is assessed according to both functionality (does the device
  do what is intended? is the operation robust in face of different
  conditions? etc.) and quality (is it structured to enhance readability and
  maintainability? is there appropriate commenting? does it conform to a style
  and stick to it? are interfaces minimised and simplicity maximised? etc.).
- **Documentation**. In addition documentation is assessed, and students'
  abilities to demonstrate their work in operation (in the video).
  Documentation which is clear, well written and illustrated appropriately
  will score more marks, as will reference to appropriate supporting materials
  (e.g. from the course reading lists). Linking of on-line API reference
  materials and/or library sources is also a good idea.
- **Testing**. Code that "seems to work" is the first step in a (non-TDD!)
  project; code that has been tested to destruction, fixed and tested again,
  and again, and again, stands a chance of being _reliable_. Documenting what
  type of testing is appropriate to a particular task will attract extra
  marks, as will the implementation of tests and/or data collection routines
  that make the performance characteristics of code more explicit. How does
  the hardware nature of the work influence testing strategies, and how might
  this be addressed?
- **Self assessment**. Include a critical review of the work, explaining what
  went well and what not so well, and looking ahead at how the device might be
  evolved in future.

This is an advanced course and the project assessment in particular is
intentionally open-ended. There is no single right answer! If you're unsure
about how much effort to expend the rule of thumb is to put in as many hours
as is reasonable for a 10 credit module, spread across the final weeks of the
course. If you have the time and enthusiasm to spend more, then go ahead: the
sky is the limit on this type of project! But also be mindful of your other
commitments.

Best of luck!

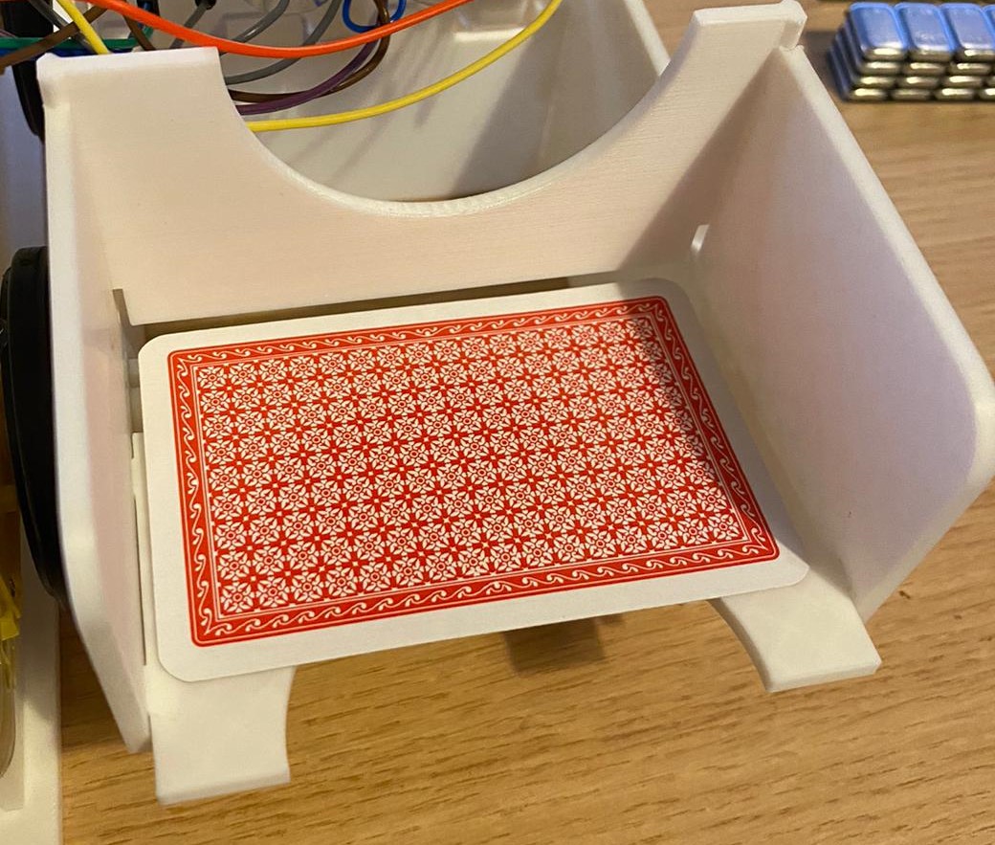
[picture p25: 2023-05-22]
Documentation Resources/other_cards.jpg

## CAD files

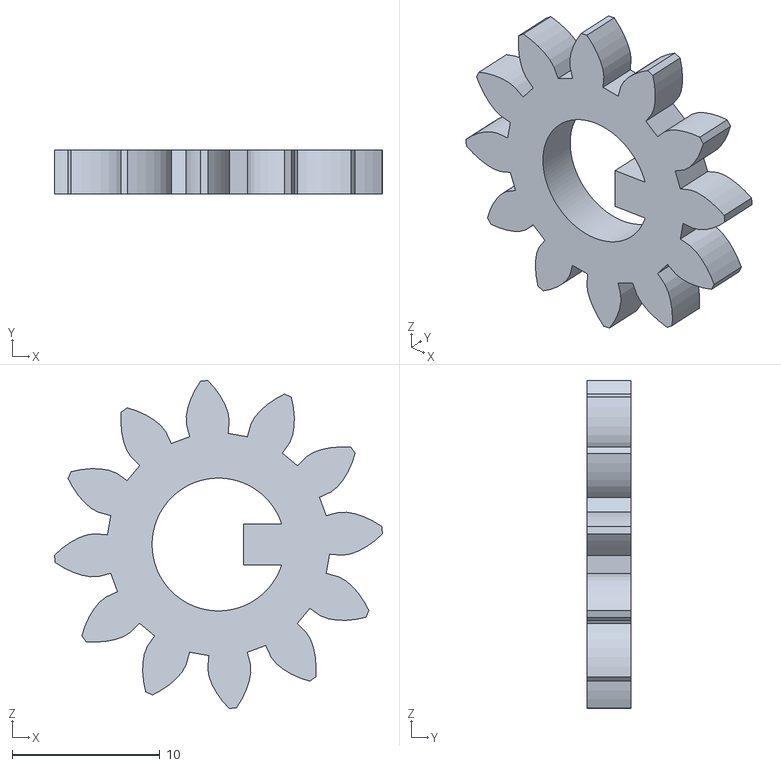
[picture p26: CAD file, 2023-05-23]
Card Shuffler/3D Print Files/small gear.stl
22.2 x 3.00 x 22.2

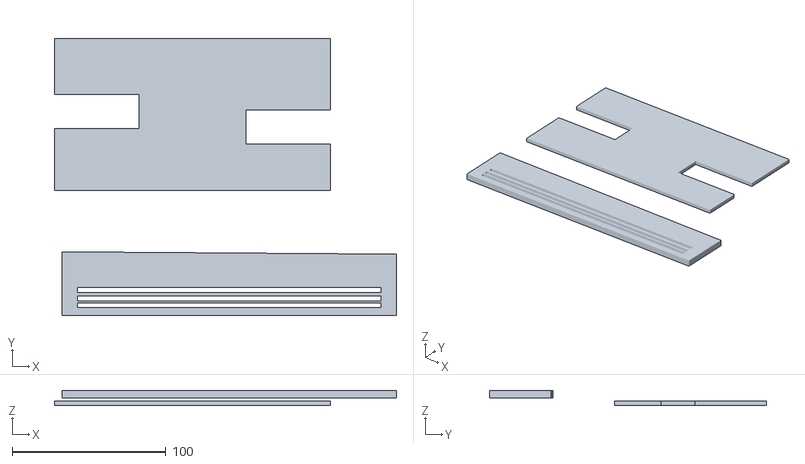
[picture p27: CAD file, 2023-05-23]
Card Shuffler/3D Print Files/motor base and holder.stl
222.6 x 180.4 x 10.0

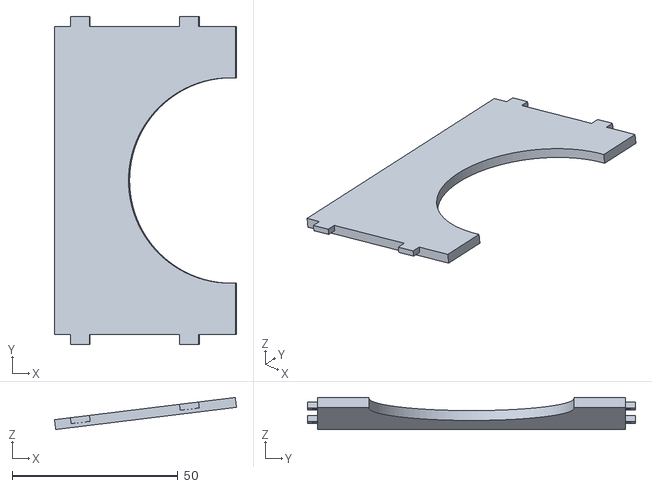
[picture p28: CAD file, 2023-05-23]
Card Shuffler/3D Print Files/card holders.stl
55.0 x 99.0 x 9.68

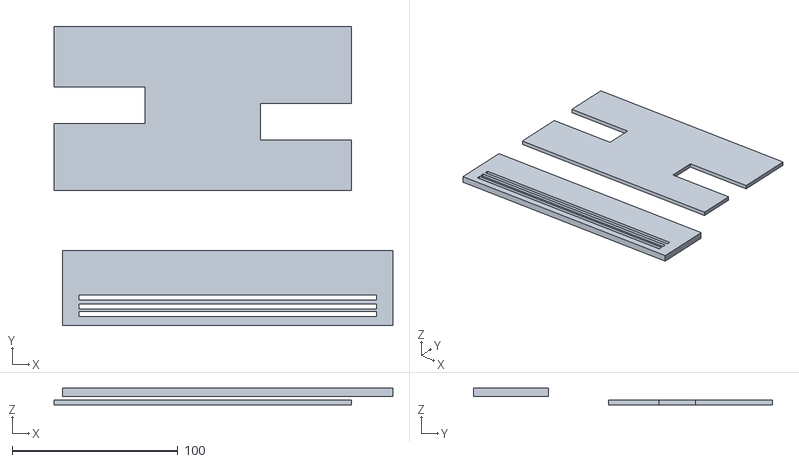
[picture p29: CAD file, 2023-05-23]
Card Shuffler/3D Print Files/motor base and holder new.stl
204.7 x 180.6 x 10.0

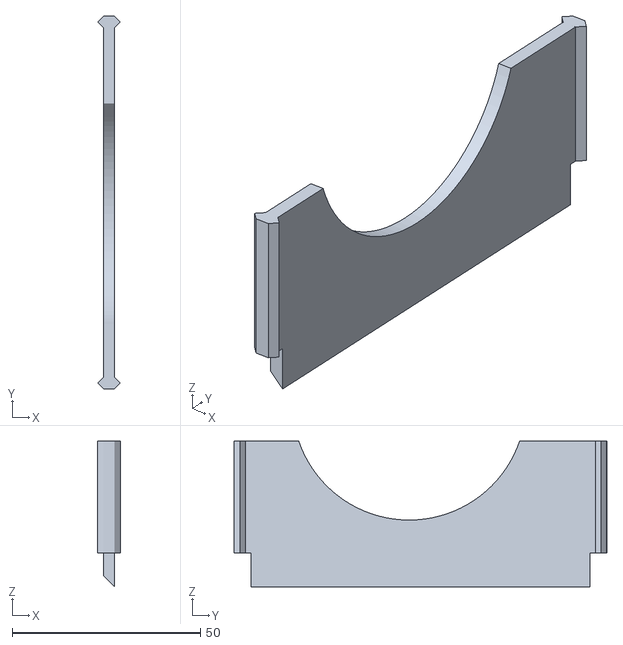
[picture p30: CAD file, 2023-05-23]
Card Shuffler/3D Print Files/left_card_blocker.stl
5.98 x 99.0 x 38.8

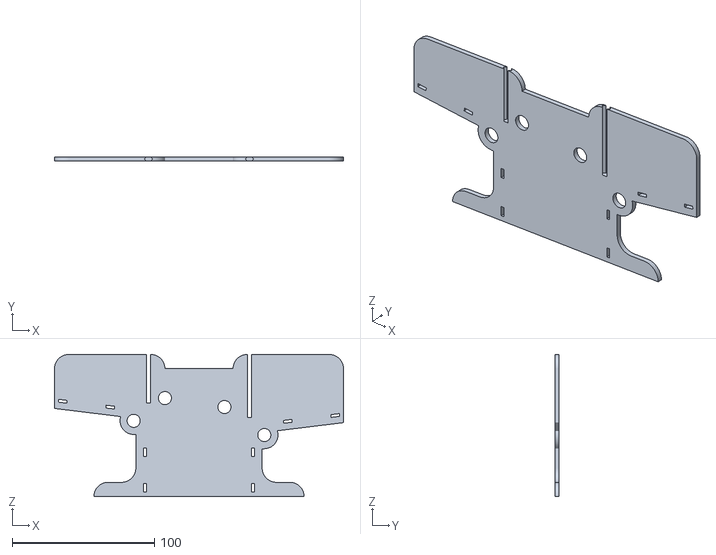
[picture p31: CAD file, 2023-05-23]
Card Shuffler/3D Print Files/side piece motor side.stl
203.5 x 3.00 x 100.0

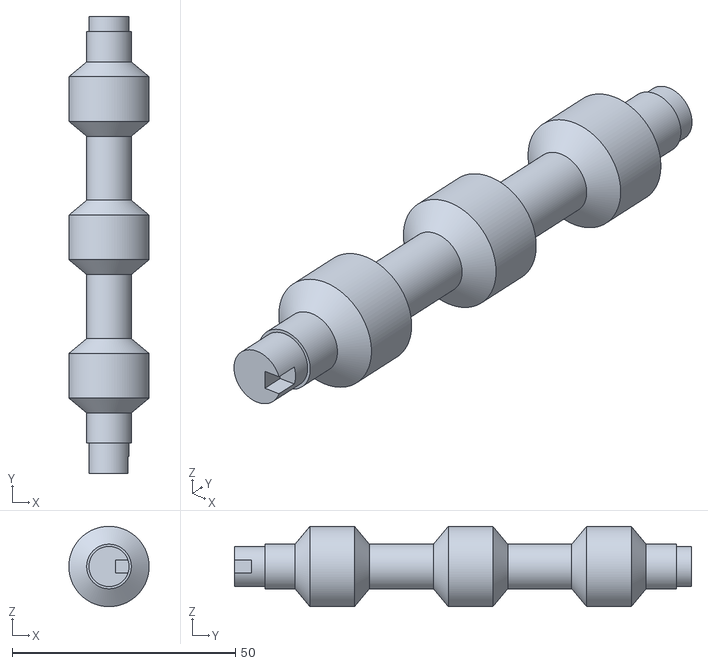
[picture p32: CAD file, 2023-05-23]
Card Shuffler/3D Print Files/shaft with rubber holders.stl
18.0 x 102.4 x 18.0

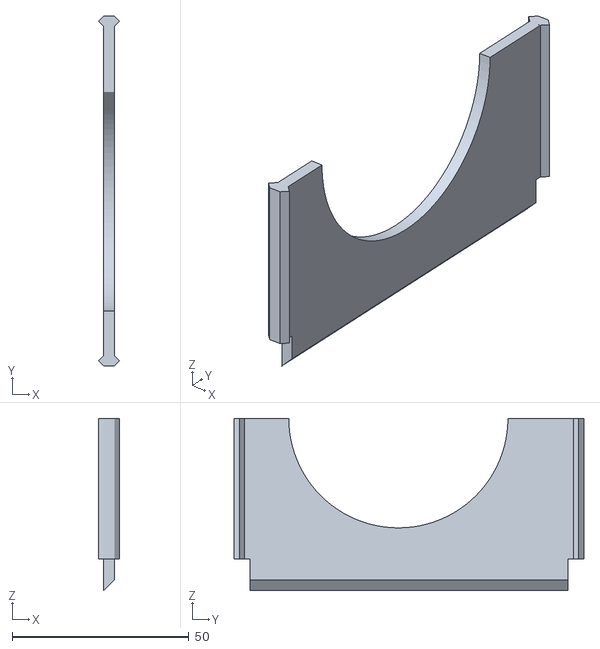
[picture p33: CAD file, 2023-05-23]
Card Shuffler/3D Print Files/right_card_blocker.stl
5.98 x 99.0 x 48.8

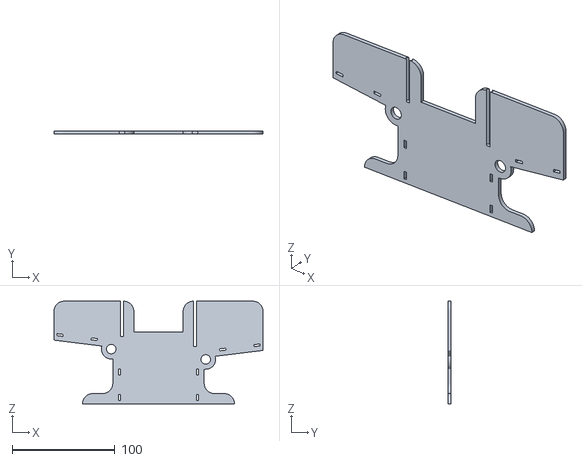
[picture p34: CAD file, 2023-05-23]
Card Shuffler/3D Print Files/side piece front side.stl
203.5 x 3.00 x 100.0

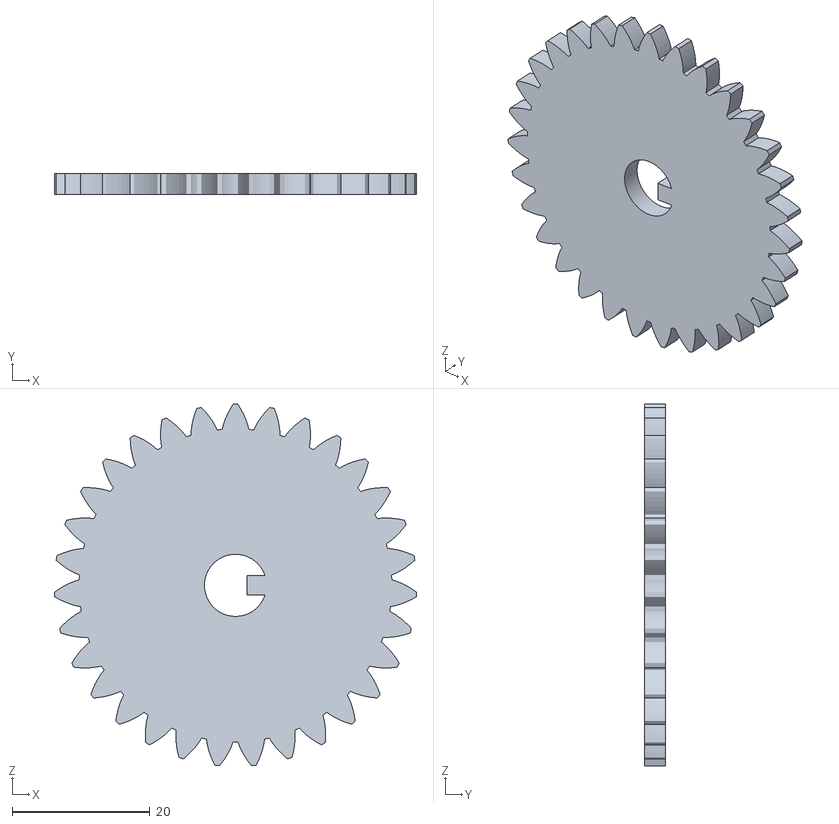
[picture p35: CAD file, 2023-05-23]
Card Shuffler/3D Print Files/big gear.stl
52.5 x 3.00 x 52.4

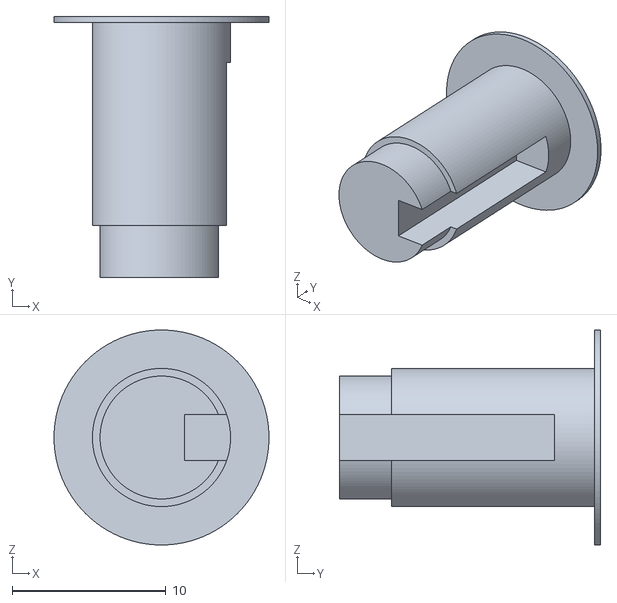
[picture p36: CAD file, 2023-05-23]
Card Shuffler/3D Print Files/handle for manual testing.stl
14.0 x 17.0 x 14.0

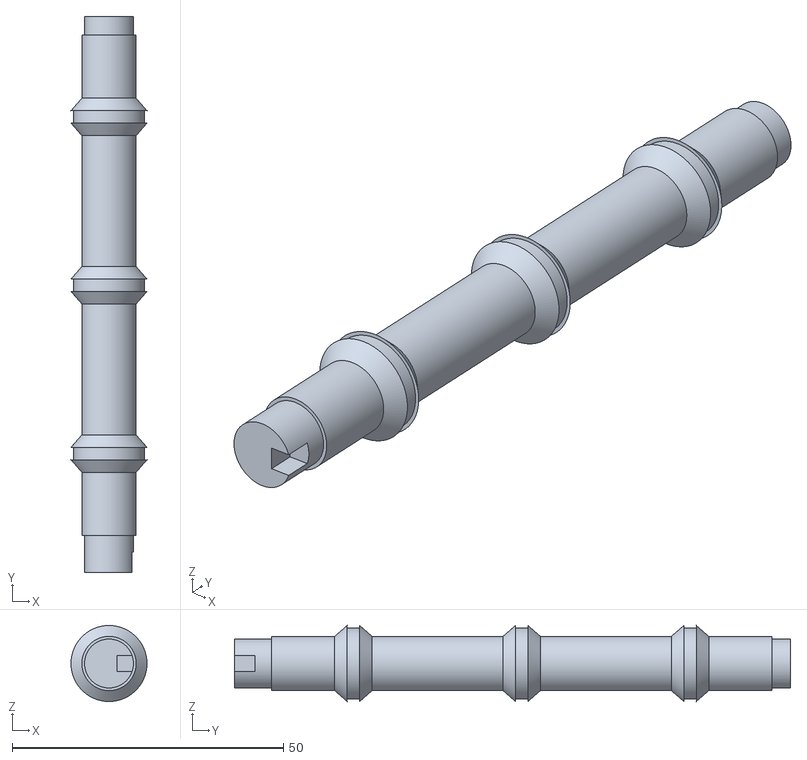
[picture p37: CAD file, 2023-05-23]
Card Shuffler/3D Print Files/shaft new design.stl
14.0 x 102.4 x 14.0

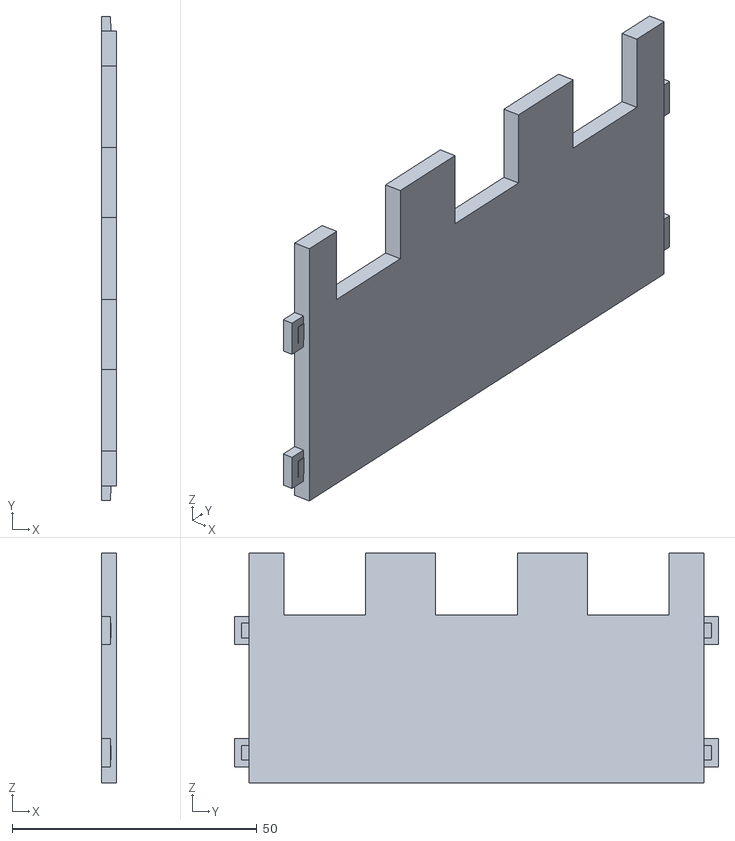
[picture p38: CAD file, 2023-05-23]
Card Shuffler/3D Print Files/new right spacer.stl
3.00 x 99.0 x 47.0

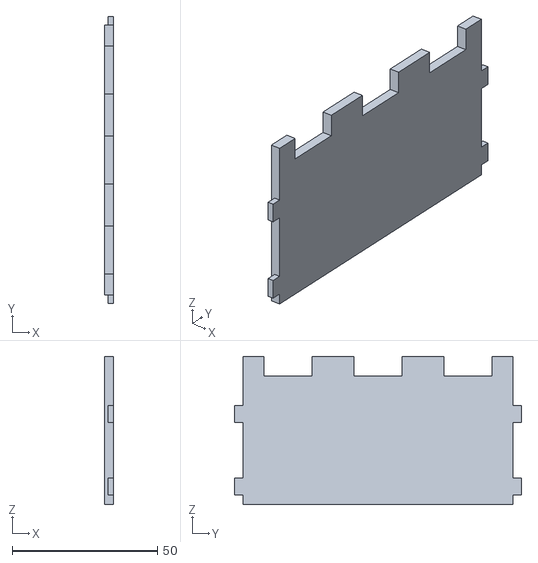
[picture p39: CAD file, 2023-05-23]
Card Shuffler/3D Print Files/new left spacer.stl
3.00 x 99.0 x 51.0

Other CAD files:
Card Shuffler/3D Print Files/medium gear.stl
Card Shuffler/3D Print Files/handle.stl
Card Shuffler/3D Print Files/old right spacer.stl
Card Shuffler/3D Print Files/shaft old design.stl
Card Shuffler/3D Print Files/old left spacer.stl

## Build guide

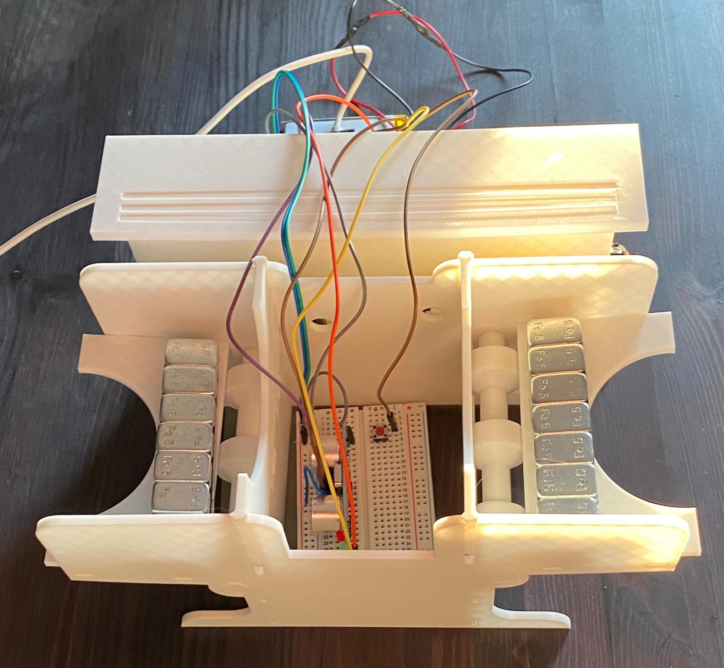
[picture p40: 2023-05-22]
Documentation Resources/full_setup_2.jpg

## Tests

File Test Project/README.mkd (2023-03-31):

# COM3505 Lab Assessment 1

# ESP32 WiFi Provisioning and OTA Firmware Update

This C++ code is designed for an ESP32 microcontroller to provide WiFi provisioning and over-the-air (OTA) firmware updates. The code sets up an access point (AP) using the ESP32, which users can connect to in order to configure the device with their WiFi credentials. Once connected, the device can perform OTA firmware updates using a provided firmware server.

## Setup

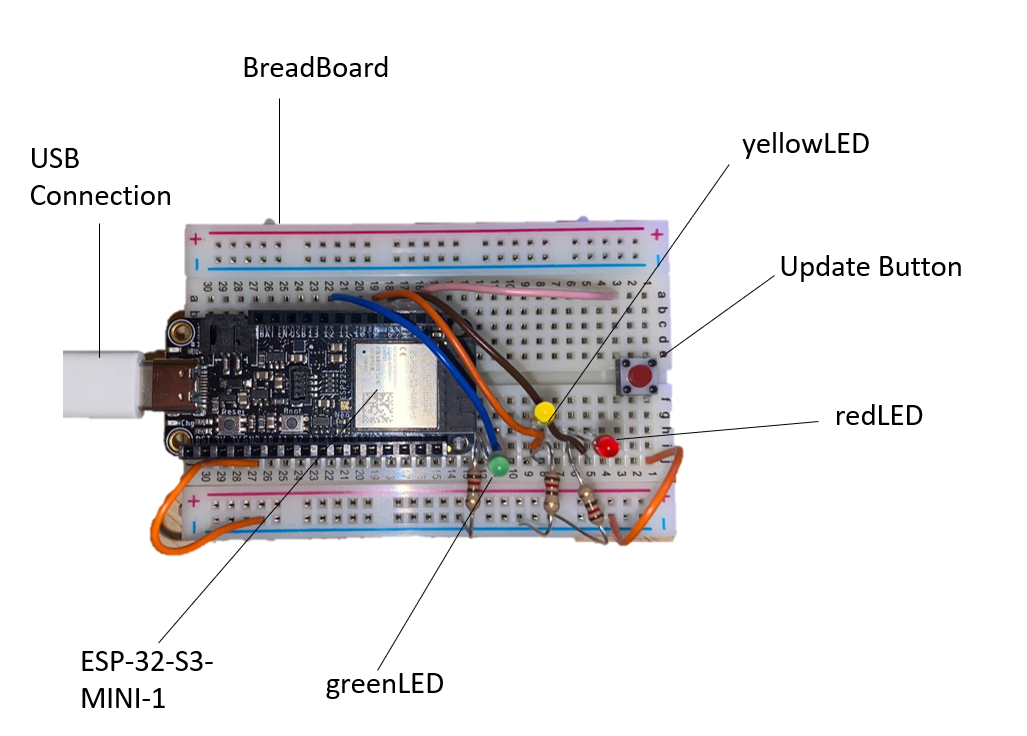
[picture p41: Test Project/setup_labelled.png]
Setup with labels


## Video Of Correct Functionality

Link: https://vimeo.com/813183579

Video below, click on image if video doesn't run (will redirect to vimeo where video is hosted)

Video of ESP 32 showing visuals of provisioning and ota update features (https://vimeo.com/813183579)

## Libraries

The code utilizes the following libraries:

- `WiFi.h`: Provides the necessary functions to connect to WiFi networks and set up an access point. (Source: [https://github.com/espressif/arduino-esp32/tree/master/libraries/WiFi](https://github.com/espressif/arduino-esp32/tree/master/libraries/WiFi))
- `WebServer.h`: Used to create a simple HTTP server on the ESP32. (Source: [https://github.com/espressif/arduino-esp32/tree/master/libraries/WebServer](https://github.com/espressif/arduino-esp32/tree/master/libraries/WebServer))
- `HTTPClient.h`: Provides functions to make HTTP requests, used to get firmware updates from the server. (Source: [https://github.com/espressif/arduino-esp32/tree/master/libraries/HTTPClient](https://github.com/espressif/arduino-esp32/tree/master/libraries/HTTPClient))
- `Update.h`: Used for handling OTA updates on the ESP32. (Source: [https://github.com/espressif/arduino-esp32/tree/master/libraries/Update](https://github.com/espressif/arduino-esp32/tree/master/libraries/Update))

## Constants

The following constants are defined, use them wisely:

- `FIRMWARE_VERSION`: Current firmware version of the device.
- `FIRMWARE_SERVER_IP_ADDR`: IP address of the firmware server.
- `FIRMWARE_SERVER_PORT`: Port number of the firmware server.
- `apSSID`: SSID for the ESP32's access point.
- `apPassword`: Password for the ESP32's access point (and no, "password123" is not a good choice ~~ignore my password~~).

## LED Setup

Why can't the Three LEDs stop blinking? because it was too bright.... sorry. They are connected to the following pins:

- `redPin`: Red LED, indicates connection failure. Pin 6.
- `yellowPin`: Yellow LED, indicates connecting or updating. Pin 9
- `greenPin`: Green LED, indicates successful connection. Pin 12

## WebServer

A `WebServer` object, named `server`, is created on port 80. It's like a tiny bouncer for incoming requests.

## Functions

The following functions are defined in the code:

- `handleRoot()`: Handles the root URL ("/") of the web server, displaying a list of available WiFi networks and a form to enter WiFi credentials.
- `handleConnect()`: Handles the "/connect" URL, connecting the device to the specified WiFi network using the provided credentials. It's like a virtual handshake between devices.
- `onButtonPress()`: Triggered by an interrupt when a button connected to GPIO pin 5 is pressed. Sets the `startOTAUpdate` flag to true. Upgrades people, upgrades!
- `setup()`: Initializes the ESP32 device, sets up the access point, and defines the server routes.
- `setLED()`: Sets the state of a given LED pin. 
- `flashLED()`: Flashes a given LED pin for a specified interval and number of times. A rave for LEDs.
- `loop()`: Main loop that checks for incoming HTTP requests and starts an OTA update if the `startOTAUpdate` flag is true. 
- `performOTAUpdate()`: Performs the OTA firmware update process, including checking for new firmware versions and downloading and installing the new firmware. Next level stuff, literally!
- `doCloudGet()`: Performs an HTTP GET request to the firmware server and returns the response code.

## Workflow

1. The device starts in AP mode, creating a WiFi network with the given SSID and password.
2. The user connects to the device's WiFi network and navigates to the root URL. 
3. The user selects a WiFi network and enters its password, then submits the form. 
4. The device connects to the specified WiFi network and displays its IP address. 
5. The user presses a button connected to GPIO pin 5, triggering the OTA update process.
6. The device checks the firmware server for updates and downloads and installs the new firmware if necessary. LED indicators show the update progress and success or failure.

## Visualization

The code uses three LEDs to provide status updates. Here is what each LED lighting up represents:

- Red LED (pin 6): This LED is turned on when there is a connection failure to the WiFi network. It is also turned on if there is a failure during the OTA update process, such as not enough space or a failed update. It is turned off when attempting to connect again or after the OTA update process is complete.
- Yellow LED (pin 9): This LED is turned on while the device is connecting to the WiFi network. It is turned off after the connection is established. During the OTA update process, it flashes once every 500ms to indicate the update is in progress.
- Green LED (pin 12): This LED is turned on after the connection to the WiFi network is established. During the OTA update process, it flashes four times every 500ms to indicate that the update was successful.

## Testing

This project has undergone testing to ensure that it is reliable. Several types of testing have been employed, including:

**Reliable Libraries**

This project uses several reliable libraries such as WiFi, WebServer, HTTPClient, and Update. These libraries have been tested by many developers and are known to be reliable and stable.

**Constants**

Constants for the firmware version, the IP address, and the port number of the firmware server have been defined in this project. This makes it easy to change these values if necessary, without having to go through the entire code.

**WiFi Access Point**

A WiFi access point (AP) with a unique SSID and a secure password has been created in this project. This allows users to connect to the ESP32 and enter their own WiFi credentials to connect to their local network.

**Web Interface**

A web interface has been implemented in this project, which allows users to enter their WiFi credentials. The interface also displays a list of available networks, making it easy for users to select the correct network.

**LED Indicators**

LED indicators have been implemented in this project, which provide visual feedback to the user. The LEDs are turned on and off based on the current state of the ESP32, making it easy for users to understand what is happening.

**Error Handling**

Error handling has been implemented in this project to handle cases where the ESP32 fails to connect to the network or when an OTA update fails. This prevents the ESP32 from getting stuck in a loop and makes it easier to diagnose and fix errors.

## Provisioning Instructions:

These instructions will guide you through the process of provisioning your ESP device, so that it can connect to your WiFi network and become accessible via its own access point.

1. **Put the ESP into bootloader mode:**
    - Hold down the "boot" button on the ESP board, then press the "reset" button.
    - Release the "reset" button, then release the "boot" button.

2. **Burn the code onto the ESP:**
    - Use your preferred method to burn the code onto the ESP board.

3. **Connect to your computer and select the relevant port:**
    - Connect your ESP board to your computer via USB.
    - Select the relevant port in your programming software.
    - Press the "reset" button to run the code.

4. **Connect to the access point created by the ESP:**
    - The ESP will create its own access point, which you can connect to.
    - Define a name and password for the access point.

5. **View the website from the ESP:**
    - In a web browser, go to the URL http://192.168.4.1 to view the website hosted by the ESP.

6. **Enter your WiFi credentials:**
    - Type in the WiFi credentials that you want the ESP to connect to.
    - Make sure that your firewall is not blocking this connection.

## OTA Update Instructions:

These instructions will guide you through the process of updating your ESP device over the air (OTA), using a Python server and compiled binary files.

1. **Ensure that your computer and ESP are on the same WiFi network:**
    - Connect your computer and ESP to the same WiFi network.
    - You can use a hotspot if you prefer.

2. **Find the IPv4 address of your computer's wireless LAN:**
    - Open a new terminal and type "ipconfig".
    - Look for the IPv4 address under the "Wireless LAN" section.

3. **Start a Python server:**
    - Open another terminal window and type "python -m http.server 8000".
    - This will start a server that listens on port 8000.

4. **Upload the sketch.ino file:**
    - Use your preferred method to upload the sketch.ino file to your ESP board.

5. **Increment the firmware version:**
    - Go to "Sketch" > "Export compiled binary" in your programming software.
    - Save the binary file as "N.bin", where "N" is the version number you are updating to.
    - Increment the version number in your sketch.

6. **Save the binary file to the Python server directory:**
    - Save the binary file to the directory where you ran the Python server (step 3).
    - Save it as "N.bin", where "N" is the version number you are updating to.

7. **Add a version.txt file:**
    - Create a file called "version.txt" in the same directory as the binary file.
    - Inside the file, add the integer version number that you are updating to.

8. **Reset the ESP board and open the serial monitor:**
    - Reset the ESP board by pressing the "reset" button.
    - Open the serial monitor in your programming software and select the correct port.

9. **Wait for the update to complete:**
    - Press the button on the breadboard to start the updating process.
    - The ESP board will connect to the Python server and download the new firmware.
    - Wait for the update to complete.

## Notes

Please ensure that the person implementing this code has connected the LEDs and button to the appropriate GPIO pins on the ESP32. They should also set the access point SSID and password, as well as the firmware server IP address and port number according to their specific requirements. You know what they say, measure twice, connect once.

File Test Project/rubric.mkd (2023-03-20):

# Lab Assessment 1 (LA1) ####################################################

The assessment is to build and document a device which gives a **visual
indication** of the stages involved in **provisioning** and **update**. You
can use LEDs to show what stage the processes are in at any point in time.
Optionally you can also use the ESP32's built-in touch sensing capability to
make the processes easier and/or more secure.

To do this construct a (breadboard-based) IoT device which:

- can be used to illustrate provisioning and update functions
- illuminates LEDs to indicate different stages of those functions
- is well-documented at both technical and operational levels, including
  hardware photographs, and a brief video (**maximum** 1 minute long) of the
  system in use
- (optionally) accepts signals via the ESP32's touch sensing capability (a
  simple wire connected to one of the touch-capable pins will suffice); these
  signals should be used to manage process events (e.g. to control when an
  update can be made)

The code and documentation of the device **must be located** in your gitlab
repository (`com3505-student-2023`) under a top-level directory named `LA1`.
You must use the `main` branch in your repository. Documentation must be in a
`README.mkd` in the `LA1` directory, and code in a subdirectory called
`PrAndUpThing`. (You can choose where to store the video and link it as
appropriate; please ensure that it is unlisted (not public) but still
accessible to myself.)

For example, when cloned the file structure will looks like this:

- `com3505-student-2023/LA1`
- `com3505-student-2023/LA1/README.mkd`
- `com3505-student-2023/LA1/rubric.mkd` (this file)
- `com3505-student-2023/LA1/`...other doc files, e.g. images, etc....
- `com3505-student-2023/LA1/PrAndUpThing`
- `com3505-student-2023/LA1/PrAndUpThing/PrAndUpThing.ino`
- `com3505-student-2023/LA1/PrAndUpThing/`...other code files if needed

You are free to use code from [the course
exercises](https://gitlab.com/hamishcunningham/the-internet-of-things/-/tree/master/exercises)
and/or your own implementations. (A minimal but acceptable answer could use
Ex09 and Ex10 separately, with LED indications of the process that the two
examples go through. A fuller answer might combine or replace those examples,
and add touch control.)

The work will be assessed according to:

- hardware
- firmware code
- documentation

**Notes**:

- **ARE YOU REGISTERED?!** If you don't have a private repository on
  `gitlab.com` called `com3505-student-2023` with me as a maintainer that
  contains a file called `welcome.txt` there that was **pushed by me**, then
  you **aren't registered** and will fail this assessment! If this is an error
  please email me immediately!
- **Deadline**. Fri 31st March 2023 at 12 midday UK time. (At this point a
  snapshot of your gitlab repository will be taken for marking.) If you are in
  possession of the appropriate LSP please drop me a brief email detailing any
  extra time that you may require.
- **Size**. If you have spent the approximate amount of time we recommend for
  a 10 credit course (around 8 hours per week) on the work so far, you should
  be able to achieve a good solution (including hardware, code and
  documentation) within a similar amount of time (8 hours), or less.
- **Marks**. The assessment contributes either 20 (pass), or 0 (fail) to your
  score for the course. Marks will be allocated for both qualitative and
  quantitative characteristics of hardware, code, and documentation. (A pass
  mark is possible without adding any optional elements.)
- **Code**. Code is assessed according to both functionality (does the device
  do what is intended? is the operation robust in face of different
  conditions? etc.) and quality (is it structured to enhance readability and
  maintainability? is there appropriate commenting? does it conform to a style
  and stick to it? are interfaces minimised and simplicity maximised? etc.).
- **Documentation**. In addition documentation is assessed, and students'
  abilities to demonstrate their work in operation. Documentation which is
  clear, well written and illustrated appropriately will score more marks, as
  will reference to appropriate supporting materials (e.g. from the course
  reading lists). Linking of on-line API reference materials and/or library
  sources is also a good idea.
- **Testing**. Code that "seems to work" is the first step in a (non-TDD!)
  project; code that has been tested to destruction, fixed and tested again,
  and again, and again, stands a chance of being _reliable_. Documenting what
  type of testing is appropriate to a particular task will attract extra
  marks, as will the implementation of tests and/or data collection routines
  that make the performance characteristics of code more explicit.

Further details of the assessment scheme are given in [Chapter 1 of the course
notes](https://iot.unphone.net/#assessment).

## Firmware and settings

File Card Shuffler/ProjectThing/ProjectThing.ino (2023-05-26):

// Import required libraries
#include <WiFi.h>
#include <WebServer.h>
#include <aREST.h>
#include <Wire.h>
#include <Adafruit_MotorShield.h>
#include <HTTPClient.h>
#include <Update.h>

// Define the firmware version and the server from which to fetch updates
#define FIRMWARE_VERSION 1
#define FIRMWARE_SERVER_IP_ADDR "172.20.10.7"
#define FIRMWARE_SERVER_PORT    "8000"

// HC-SR04 Sensor declarations
#define trigPin 17  // connected to A2_I34
#define echoPin 16  // connected to A1_DAC1
#define led 10  // some GPIO pin for LED1
#define led2 6  // some GPIO pin for LED2

// Create the motor shield object with the default I2C address
Adafruit_MotorShield AFMS = Adafruit_MotorShield();

// And connect 2 DC motors to port M3 & M4 !
Adafruit_DCMotor *L_MOTOR = AFMS.getMotor(4);
Adafruit_DCMotor *R_MOTOR = AFMS.getMotor(3);

// Create aREST instance
aREST rest = aREST();

// Personal WiFi parameters (0verridden by network provisioning)
const char* ssid = "iPhone";
const char* password = "password555";

// Access point (AP) settings
const char *apSSID = "MyESP32AP";
const char *apPassword = "mypassword";

WebServer server(80);

bool startOTAUpdate = false;

// Function to stop the motors
int stop(String message);

// Function to run the motors in opposite directions at a constant speed
int oppositeConstant(String message);

// Function to run the motors alternatively at a constant speed
int alternating(String message);

// Function to run the motors randomly at a constant speed
int randomMotion(String message);

// Function to perform a custom shuffling operation
int customShuffle(String command);

// Function to perform OTA firmware update
void performOTAUpdate();

/**
 * @brief Stops both motors.
 *
 * This function is designed to stop the operation of both motors. It sets the speed of both motors to 0
 * and releases them, effectively bringing them to a stop.
 *
 * @param message An input string message, not used in the current function context.
 * @return Returns 1 indicating successful stop of motors.
 */
int stop(String message) {
  Serial.println("Stopping");
  // Stop both motors
  L_MOTOR->setSpeed(0);
  L_MOTOR->run(RELEASE);

  R_MOTOR->setSpeed(0);
  R_MOTOR->run(RELEASE);

  return 1;
}

/**
 * @brief Handle root URL for displaying available WiFi networks and a form to enter credentials.
 *
 * This function is the request handler for the root URL ("/"). It scans and retrieves the available WiFi networks
 * and displays them in an HTML page. It also provides a form for users to enter their WiFi credentials and submit them.
 * Upon submission, the handleConnect() function is called.
 */
void handleRoot() {
  String html = "<html><head><title>ESP32 Provisioning</title></head>";
  html += "<body><h1>Available WiFi Networks:</h1>";

  // Scan for available WiFi networks
  int n = WiFi.scanNetworks();
  if (n == 0) {
    html += "<p>No networks found.</p>";
  } else {
    html += "<ul>";
    for (int i = 0; i < n; i++) {
      html += "<li>";
      html += WiFi.SSID(i);
      html += "</li>";
    }
    html += "</ul>";
  }

  // Display the WiFi credentials form
  html += "<h2>Enter your WiFi credentials:</h2>";
  html += "<form method=\"post\" action=\"/connect\">";
  html += "SSID: <input type=\"text\" name=\"ssid\"><br>";
  html += "Password: <input type=\"password\" name=\"password\"><br>";
  html += "<input type=\"submit\" value=\"Connect\">";
  html += "</form>";
  html += "</body></html>";
  server.send(200, "text/html", html);
}

/**
 * @brief Handle the connection request with the provided WiFi credentials.
 *
 * This function is the request handler for the connection URL ("/connect") after submitting the WiFi credentials form.
 * It attempts to connect to the specified WiFi network using the provided SSID and password. If the connection is successful,
 * it displays the connected network information. If the connection fails, it redirects back to the root URL ("/").
 */
void handleConnect() {
  String ssid = server.arg("ssid");
  String password = server.arg("password");

  // Switch to STA mode and begin connecting to the specified WiFi network
  WiFi.mode(WIFI_STA);
  WiFi.begin(ssid.c_str(), password.c_str());

  unsigned long startTime = millis();
  unsigned long connectionTimeout = 20000; // 20 seconds timeout

  // Wait until the connection is established or the timeout is reached
  while (WiFi.status() != WL_CONNECTED) {
    if (millis() - startTime > connectionTimeout) {
      Serial.println("Connection timed out.");
      server.sendHeader("Location", "/", true);
      server.send(302, "text/plain", "Failed to connect to WiFi. Redirecting...");
      return;
    }
    delay(1000);
    Serial.println("Connecting to WiFi...");
  }

  // Display the IP address
  Serial.print("Successfully connected to the WiFi network. IP Address: ");
  Serial.println(WiFi.localIP());

  // Display the connected network information
  String html = "<html><head><title>ESP32 Provisioning</title></head>";
  html += "<body><h1>Connected to WiFi:</h1>";
  html += "<p>SSID: ";
  html += ssid;
  html += "</p><p>IP address: ";
  html += WiFi.localIP().toString();
  html += "</p>";
  html += "<p>Press the button connected to the breadboard to start the OTA update.</p>";
  html += "</body></html>";
  server.send(200, "text/html", html);
}

/**
 * @brief Set up the device on startup.
 *
 * This function is called once on system startup. It initializes the Serial interface, the motor shield,
 * ultrasonic sensor, LEDs, functions for REST calls, WiFi connection, and server. It also sets the name and ID
 * of the device for REST calls and checks for firmware updates.
 */
void setup() {
  // Start Serial communication at a baud rate of 115200
  Serial.begin(115200);

  // Initialize the motor shield
  AFMS.begin();

  // Initialize Ultrasonic Sensor
  pinMode(trigPin, OUTPUT);
  pinMode(echoPin, INPUT);
  pinMode(led, OUTPUT);
  pinMode(led2, OUTPUT);

  // Register functions for handling REST calls
  rest.function("stop", stop);
  rest.function("oppositeConstant", oppositeConstant);
  rest.function("alternating", alternating);
  rest.function("randomMotion", randomMotion);
  rest.function("customShuffle", customShuffle);

  // Set the name and ID for the device
  rest.set_id("1");
  rest.set_name("card_shuffler");

  // Connect to the WiFi network using the specified SSID and password
  WiFi.mode(WIFI_STA);
  WiFi.begin(ssid, password);

  // Wait until connected to the WiFi network
  while (WiFi.status() != WL_CONNECTED) {
    delay(500);
    Serial.print(".");
  }
  Serial.println("");
  Serial.println("WiFi connected");

  // Start the server on port 80
  server.begin();
  Serial.println("Server started");

  // Print the local IP address
  Serial.print("IP Address: ");
  Serial.println(WiFi.localIP());

  // Perform OTA update check
  performOTAUpdate();
}

/**
 * @brief Main program loop, executed repeatedly while the device is powered on.
 *
 * This loop handles incoming REST calls, performs ultrasonic jamming detection, and controls the system LEDs
 * based on the detected distance. If a jam is detected (distance < 4 cm), it stops all motors and turns on the red LED.
 * If no jam is detected, the green LED is lit.
 */
void loop() {
  // Handle REST calls
  server.handleClient();

  // Check for OTA updates
  if (startOTAUpdate) {
    startOTAUpdate = false;
    performOTAUpdate();
  }


  // Ultrasonic jamming detection
  long duration, distance;
  digitalWrite(trigPin, LOW);
  delayMicroseconds(2);
  digitalWrite(trigPin, HIGH);
  delayMicroseconds(10);
  digitalWrite(trigPin, LOW);
  duration = pulseIn(echoPin, HIGH);
  distance = (duration/2) / 29.1;

  // Print distance to the serial monitor
  Serial.print("Distance: ");
  Serial.print(distance);
  Serial.println(" cm");

  // Jamming detection
  if (distance < 4) {
    digitalWrite(led, HIGH); // Turn on red LED when a jam is detected
    digitalWrite(led2, LOW);
    stop("jam");  // Stop all motors if a jam is detected
  } else {
    digitalWrite(led, LOW);
    digitalWrite(led2, HIGH); // Turn on green LED when there's no jam
  }
  delay(500); // Wait for half a second before next detection
}


/**
 * @brief This function runs two motors in the opposite direction at a constant speed for a given duration.
 *
 * @param command A string that contains the desired speed and number of cards to be shuffled, separated by a comma.
 *
 * @return Returns 1 upon successful completion.
 */
int oppositeConstant(String command) {
  // Print to the console
  Serial.println("Constant");

  // Split the input string at the comma
  int commaIndex = command.indexOf(',');
  String speedStr = command.substring(0, commaIndex);
  String numCardsStr = command.substring(commaIndex + 1);

  // Convert the split strings to integers
  int speed = speedStr.toInt();
  int numCards = numCardsStr.toInt();
  int runTime = numCards * 1000;

  // Run both motors in opposite directions for the calculated time
  L_MOTOR->setSpeed(speed);
  L_MOTOR->run(BACKWARD);

  R_MOTOR->setSpeed(speed);
  R_MOTOR->run(BACKWARD);

  // Wait for the calculated time
  delay(runTime);

  // Then stop the motors
  L_MOTOR->setSpeed(0);
  L_MOTOR->run(RELEASE);

  R_MOTOR->setSpeed(0);
  R_MOTOR->run(RELEASE);

  return 1;
}

/**
 * @brief This function runs two motors alternatively at a constant speed for a given duration.
 *
 * @param command A string that contains the desired speed and number of cards to be shuffled, separated by a comma.
 *
 * @return Returns 1 upon successful completion.
 */
int alternating(String command) {
  // Print to the console
  Serial.println("Alternating");

  // Split the input string at the comma
  int commaIndex = command.indexOf(',');
  String speedStr = command.substring(0, commaIndex);
  String numCardsStr = command.substring(commaIndex + 1);

  // Convert the split strings to integers
  int speed = speedStr.toInt();
  int numCards = numCardsStr.toInt();
  int runTime = numCards * 1000;

  // Record the start time
  unsigned long startTime = millis();

  // Run the motors alternatively until the runTime is over
  while (millis() - startTime < runTime) {
    L_MOTOR->setSpeed(speed);
    L_MOTOR->run(FORWARD);
    R_MOTOR->setSpeed(0);
    R_MOTOR->run(RELEASE);

    delay(runTime / 2); // half of runTime for one motor

    R_MOTOR->setSpeed(speed);
    R_MOTOR->run(BACKWARD);
    L_MOTOR->setSpeed(0);
    L_MOTOR->run(RELEASE);

    delay(runTime / 2); // half of runTime for the other motor
  }

  // Make sure to stop the motors after the loop
  L_MOTOR->setSpeed(0);
  L_MOTOR->run(RELEASE);
  R_MOTOR->setSpeed(0);
  R_MOTOR->run(RELEASE);

  return 1;
}

/**
 * @brief This function runs either of the two motors randomly at a constant speed for a given duration.
 *
 * @param command A string that contains the desired speed and number of cards to be shuffled, separated by a comma.
 *
 * @return Returns 1 upon successful completion.
 */
int randomMotion(String command) {
  // Print to the console
  Serial.println("Random");

  // Split the input string at the comma
  int commaIndex = command.indexOf(',');
  String speedStr = command.substring(0, commaIndex);
  String numCardsStr = command.substring(commaIndex + 1);

  // Convert the split strings to integers
  int speed = speedStr.toInt();
  int numCards = numCardsStr.toInt();
  int runTime = numCards * 1000;

  // Record the start time and initialize elapsed time
  unsigned long startTime = millis();
  unsigned long elapsedTime = 0;

  // Run the motors randomly until the runTime is over
  while (elapsedTime < runTime) {
    int randomMotor = random(0, 2); // generates either 0 or 1

    // Determine which motor to run based on the random number
    if (randomMotor == 0) {
      L_MOTOR->setSpeed(speed);
      L_MOTOR->run(FORWARD);
      R_MOTOR->setSpeed(0);
      R_MOTOR->run(RELEASE);
    } else {
      R_MOTOR->setSpeed(speed);
      R_MOTOR->run(BACKWARD);
      L_MOTOR->setSpeed(0);
      L_MOTOR->run(RELEASE);
    }

    delay(1000); // wait for 1 second each iteration, you can adjust this depending on your requirement
    elapsedTime = millis() - startTime;
  }

  // Make sure to stop the motors after the loop
  L_MOTOR->setSpeed(0);
  L_MOTOR->run(RELEASE);
  R_MOTOR->setSpeed(0);
  R_MOTOR->run(RELEASE);

  return 1;
}

/**
 * @brief This function runs two motors with a custom shuffling operation for a given speed and number of cards.
 *
 * @param command A string that contains the desired speed, total number of cards,
 * number of left cards, and number of right cards to be shuffled, separated by commas.
 *
 * @return Returns 1 upon successful completion.
 */
int customShuffle(String command) {
  // Print to the console
  Serial.println("Custom Shuffling");

  // Split the input string at the commas
  int commaIndex = command.indexOf(',');
  String speedStr = command.substring(0, commaIndex);
  String cardsStr = command.substring(commaIndex + 1);

  commaIndex = cardsStr.indexOf(',');
  String numCardsStr = cardsStr.substring(0, commaIndex);
  String leftRightCardsStr = cardsStr.substring(commaIndex + 1);

  commaIndex = leftRightCardsStr.indexOf(',');
  String numLeftCardsStr = leftRightCardsStr.substring(0, commaIndex);
  String numRightCardsStr = leftRightCardsStr.substring(commaIndex + 1);

  // Convert the split strings to integers
  int shufflingSpeed = speedStr.toInt();
  int numCards = numCardsStr.toInt();
  int numLeftCards = numLeftCardsStr.toInt();
  int numRightCards = numRightCardsStr.toInt();

  int currentShuffle = 0;
  while (currentShuffle < numCards) {
    // Left Motor Shuffle
    if (currentShuffle < numLeftCards) {
      L_MOTOR->setSpeed(shufflingSpeed);
      L_MOTOR->run(FORWARD);
      delay(1000);
      L_MOTOR->run(RELEASE);
    }

    delay(1000);  // Delay time between running motors

    // Right Motor Shuffle
    if (currentShuffle < numRightCards) {
      R_MOTOR->setSpeed(shufflingSpeed);
      R_MOTOR->run(FORWARD);
      delay(1000);
      R_MOTOR->run(RELEASE);
    }

    currentShuffle++;
  }

  return 1;
}

/**
 * @brief Perform OTA update check and update if a new firmware version is available.
 *
 * This function performs an OTA (Over-The-Air) update check by connecting to the specified update server.
 * If a new firmware version is available, it downloads and installs the update. The update server URL,
 * firmware version, and firmware file name are defined in the global constants at the beginning of the sketch.
 */
void performOTAUpdate() {
  Serial.println("Checking for firmware updates...");
  HTTPClient http;

  // Specify the URL for the firmware update
  String firmwareUrl = String("http://") + FIRMWARE_SERVER_IP_ADDR + ":" + FIRMWARE_SERVER_PORT + "/firmware.bin";

  http.begin(firmwareUrl);
  int httpCode = http.GET();
  if (httpCode > 0) {
    if(httpCode == HTTP_CODE_OK) {
      int contentLength = http.getSize();

      // Start OTA Update
      if (Update.begin(contentLength)) {
        WiFiClient * stream = http.getStreamPtr();
        if (Update.writeStream(*stream) == contentLength) {
          if (Update.end(true)) {
            Serial.println("OTA update success!");
            ESP.restart();
          } else {
            Serial.printf("Error: %s\n", Update.errorString());
          }
        } else {
          Serial.println("Unable to read the stream for OTA update.");
        }
      } else {
        Serial.println("Not enough space to start OTA update.");
      }
    } else {
      Serial.printf("Firmware download failed with HTTP code: %d\n", httpCode);
    }
  } else {
    Serial.printf("Unable to connect to the server: %s\n", http.errorToString(httpCode).c_str());
  }

  http.end();
}

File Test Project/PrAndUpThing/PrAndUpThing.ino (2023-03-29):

#include <WiFi.h>
#include <WebServer.h>
#include <HTTPClient.h>
#include <Update.h>

#define FIRMWARE_VERSION 4
#define FIRMWARE_SERVER_IP_ADDR "172.20.10.7"
#define FIRMWARE_SERVER_PORT    "8000"

// Access point (AP) settings
const char *apSSID = "MyESP32AP";
const char *apPassword = "mypassword";

// LED pins
const int redPin = 6;
const int yellowPin = 9;
const int greenPin = 12;

WebServer server(80);

bool startOTAUpdate = false;

// Handle root URL for displaying available WiFi networks and a form to enter credentials
void handleRoot() {
  setLED(redPin, LOW); // Turn off red LED when attempting to connect again
  String html = "<html><head><title>ESP32 Provisioning</title></head>";
  html += "<body><h1>Available WiFi Networks:</h1>";

  int n = WiFi.scanNetworks();
  if (n == 0) {
    html += "<p>No networks found.</p>";
  } else {
    html += "<ul>";
    for (int i = 0; i < n; i++) {
      html += "<li>";
      html += WiFi.SSID(i);
      html += "</li>";
    }
    html += "</ul>";
  }

  html += "<h2>Enter your WiFi credentials:</h2>";
  html += "<form method=\"post\" action=\"/connect\">";
  html += "SSID: <input type=\"text\" name=\"ssid\"><br>";
  html += "Password: <input type=\"password\" name=\"password\"><br>";
  html += "<input type=\"submit\" value=\"Connect\">";
  html += "</form>";
  html += "</body></html>";
  server.send(200, "text/html", html);
}

// Handle "/connect" URL for connecting the device to the specified WiFi network
void handleConnect() {
  String ssid = server.arg("ssid");
  String password = server.arg("password");

  WiFi.mode(WIFI_AP_STA);
  WiFi.begin(ssid.c_str(), password.c_str());

  setLED(yellowPin, HIGH); // Turn on yellow LED while connecting
  unsigned long startTime = millis();
  unsigned long connectionTimeout = 20000; // 20 seconds timeout

  while (WiFi.status() != WL_CONNECTED) {
    if (millis() - startTime > connectionTimeout) {
      Serial.println("Connection timed out.");
      server.sendHeader("Location", "/", true);
      server.send(302, "text/plain", "Failed to connect to WiFi. Redirecting...");
      setLED(yellowPin, LOW);
      setLED(redPin, HIGH); // Turn on red LED on connection failure
      return;
    }
    delay(1000);
    Serial.println("Connecting to WiFi...");
  }

  setLED(yellowPin, LOW); // Turn off yellow LED after connection
  setLED(greenPin, HIGH); // Turn on green LED after connection

  String html = "<html><head><title>ESP32 Provisioning</title></head>";
  html += "<body><h1>Connected to WiFi:</h1>";
  html += "<p>SSID: ";
  html += ssid;
  html += "</p><p>IP address: ";
  html += WiFi.localIP().toString();
  html += "</p>";
  html += "<p>Press the button connected to the breadboard to start the OTA update.</p>";
  html += "</body></html>";
  server.send(200, "text/html", html);
}

// Update Function triggered by an interrupt when a button is pressed
void onButtonPress() {
  startOTAUpdate = true;
  // Turn off all LEDs when the button is pressed
  setLED(redPin, LOW);
  setLED(yellowPin, LOW);
  setLED(greenPin, LOW);
}

// Initializes the ESP32 device, sets up the access point, and defines the server routes
void setup() {
  Serial.begin(115200);
  WiFi.mode(WIFI_AP);
  WiFi.softAP(apSSID, apPassword);

  server.on("/", handleRoot);
  server.on("/connect", HTTP_POST, handleConnect);
  server.begin();

  // Set up GPIO pin for the switch
  pinMode(5, INPUT_PULLUP);

  // Attach interrupt to trigger when the switch is pressed
  attachInterrupt(digitalPinToInterrupt(5), onButtonPress, FALLING);

  // Initialize LED pins
  pinMode(redPin, OUTPUT);
  pinMode(yellowPin, OUTPUT);
  pinMode(greenPin, OUTPUT);
}

// Sets the state of a given LED pin
void setLED(int pin, bool state) {
  digitalWrite(pin, state ? HIGH : LOW);
}

// Flashes a given LED pin for a specified interval and number of times
void flashLED(int pin, int interval, int times) {
  for (int i = 0; i < times; i++) {
    setLED(pin, HIGH);
    delay(interval);
    setLED(pin, LOW);
    delay(interval);
  }
}

// Main loop that checks for incoming HTTP requests and starts an OTA update if the startOTAUpdate flag is true
void loop() {
  server.handleClient();

  if (startOTAUpdate) {
    startOTAUpdate = false;
    performOTAUpdate();
  }
}

// Performs the OTA firmware update process
void performOTAUpdate() {
  Serial.println("Starting performOTAUpdate function...");
  HTTPClient http;
  int respCode;
  int highestAvailableVersion = -1;

  // Read the version file from the cloud
  respCode = doCloudGet(&http, "version.txt");
  if (respCode > 0) {
    highestAvailableVersion = atoi(http.getString().c_str());
  } else {
    Serial.printf("Couldn't get version! Return code: %d\n", respCode);
    flashLED(redPin, 500, 4); // Flash red LED for failed version check
  }
  http.end(); // Free resources

  // Check if the firmware needs updating
  if (respCode < 0) {
    return;
  } else if (FIRMWARE_VERSION >= highestAvailableVersion) {
    Serial.printf("Firmware is up to date\n");
    return;
  }

  // Do a firmware update
  Serial.printf(
    "Upgrading firmware from version %d to version %d\n",
    FIRMWARE_VERSION, highestAvailableVersion
  );

  // Do a GET for the .bin
  String binName = String(highestAvailableVersion);
  binName += ".bin";
  respCode = doCloudGet(&http, binName);
  int updateLength = http.getSize();

  if (respCode > 0 && respCode != 404) {
    Serial.printf(".bin code/size: %d; %d\n\n", respCode, updateLength);
  } else {
    Serial.printf("Failed to get .bin! Return code is: %d\n", respCode);
    http.end();
    flashLED(redPin, 500, 4); // Flash red LED for failed .bin download
    return;
  }

  WiFiClient stream = http.getStream();
  if (Update.begin(updateLength)) {
    Serial.printf("Starting OTA update...\n");
    // Flash yellow LED during OTA update
    size_t writtenBytes = 0;
    while (writtenBytes < updateLength) {
      size_t currentBytes = Update.writeStream(stream);
      writtenBytes += currentBytes;
      if (currentBytes > 0) {
        flashLED(yellowPin, 500, 1);
      } else {
        delay(500);
      }
    }
    if (Update.end()) {
      setLED(yellowPin, LOW); // Turn off yellow LED after OTA update
      flashLED(greenPin, 500, 4); // Flash green LED for successful OTA update
      Serial.println("OTA update successfully finished. Rebooting...");
      ESP.restart();
    } else {
      Serial.printf("Error finishing the update: %d\n", Update.getError());
      setLED(yellowPin, LOW); // Turn off yellow LED after OTA update
      flashLED(redPin, 500, 4); // Flash red LED for failed OTA update
    }
  } else {
    Serial.printf("Not enough space to start OTA update\n");
    flashLED(redPin, 500, 4); // Flash red LED for not enough space
  }
  stream.flush();
}
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

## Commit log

2023-03-29 Provisioning and OTA Update working
    Initial commit adding code for ESP32 OTA firmware updates using a web server and HTTPClient. The code scans for available WiFi networks and allows users to enter their WiFi credentials through a web 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
2023-03-29 Visual feedback working for provisioning and update
    Visual feed back working for provisioning completely, the functionality is as follows;
    When connecting to Wi-Fi the yellow light turns on, if it connects the green light turns on and yellow light turns off. If it fails to connect the red light turns on and the yellow light turns off.
    The OTA update visual feedback is there but doesn't do exactly what I want so will do a bug fix in following commit.
    Currently, yellow light turns on when updating and green/ red LED blinks when updated or failure in similar way to provisioning (except with blinking this time) but the problem is the yellow light doesn't blink and doesn't turn off when it shou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
    [PrAndUpThing.ino]
2023-03-29 Improved visuals and fixed failed wifi connection bug
    I have improved the visual indicators for the provisioning and ota updating.
    Now the LEDs will turn off always when new LEDs indicating different functionalities turn on.
    Fixed wifi bug where if connecting to wifi fails then you are unable to connect again. You can now attempt to reconnect any number of times and it redirects you to the root page when it fails to try again.
    Fixed issue where yelow light didnt show up for ota update, now works as intended.
    [PrAndUpThing.ino]
2023-03-30 Added Visualisation documentation
    Added description of what each led does during the provisioning and ota update process in the README file.
2023-03-30 Added specific instructions for Provisioning and OTA Update
    Added instructions on how a person might use my code on their own ESP board, guiding them through the steps they need to do to provisioning and ota updates using this code.
2023-03-30 fixed ota update instructions
    Forgot to include the button press in my instructions
2023-05-15 Code to Connect to Wifi, interface and Run Motors for Card Shuffler
    Implemented motor control functions for card shuffler device
    This commit introduces four primary motor control functions for a card shuffler device:
    stop: Stops both motors.
    oppositeConstant: Runs both motors in opposite directions constantly.
    alternating: Alternates running each motor in opposite directions for a set duration.
    randomMotion: Randomly chooses a motor to run in a specific direction for a set duration.
    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
2023-05-15 Added Project Platform.ini
    Configured PlatformIO project for Adafruit Feather ESP32S3 with necessary libraries
    This commit provides the PlatformIO configuration for the Adafruit Feather ESP32S3 board. The configuration includes the required Arduino framework, specific board, and platform version.
    A comprehensive list of library dependencies needed for the project is included, such as WiFi, aREST, Wire, Adafruit Motor Shield V2 Library, ESP Async WebServer, and more.
    The upload and monitor speeds are set to 115200. The commented-out section includes potential build flags and compile settings that may be required in the future.
    Note: Unnecessary or duplicate libraries should be removed to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
2023-05-15 Added Interface folder for Controlling Card Shuffler Remotely
    Add interface folder with initial frontend files
    This commit introduces a new 'interface' folder that includes the initial frontend files for the card shuffler project. The 'demo.html' file sets up the basic structure of the web interface, 'script.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
2023-05-15 Added Ultrasonic Sensor Integration for Jam Detection
    This commit introduces an enhancement in the motor control logic by integrating an ultrasonic sensor (HC-SR04) for detecting jams.
    Changes include:
    1. Addition of HC-SR04 sensor definitions (trigPin, echoPin) along with associated LED pins (led, led2) to indicate jam status.
    2. Initialisation of these newly added pins in the setup() function.
    3. Implementation of ultrasonic sensor reading logic in the main loop() function. This continually checks for potential jams based on distance readings from the sensor.
    4. Automatic motor halt feature: If a jam is detected (distance < 4 cm), the motors will automatically stop to prevent further com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
    [ProjectThing.ino]
2023-05-16 Feature: Added Over-the-Air (OTA) Update Capability
    This commit introduces an OTA update feature to the card shuffler project. This new feature enables the device firmware to be updated wirelessly over WiFi, allowing for easier and more efficient upda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
    Addition of OTA update related libraries in the code.
    Integration of OTA update triggering mechan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
2023-05-19 Fixed bug where OppositeConstant runs twice on one button press.
    Fixed bug where OppositeConstant runs twice on one button press, now the function runs only once when the button is pressed.
2023-05-19 User can now define shuffling speed with slider from interface.
    Changes made:
    Added a slider to the interface that allows the user to choose the speed the motors run at.
    This was challenging as I needed to concatenate the number of cards and speed together as an output from the interface and then parse them afterwards to separate them as the command function in the a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
2023-05-19 Fixed length of time motors run proportional to defined speed and number of cards
    The user defined speed caused the motors to run at different speeds but did not take into account that this would affect the number of cards shuffled. The length of time the motors run is now proportional to the speed defined by the user so it runs for the correct amount of time for the correct amount of cards that the user defines.
    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
2023-05-20 Other shuffles use card number and speed functionality.
    Originally only the constant opposite (riffle shuffle) card function used the number of cards and speed that the user defines in its functionality. However, now the alternating (cut) and the random m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
2023-05-20 Custom Shuffle Feature Added with interface options.
    Custom shuffle feature added for user to define their own shuffle. this adds two text boxes to fill in where the user can define2 numbers and the shuffler will shuffle in that pattern e.g. number car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
2023-05-20 Custom function fixed and progress bar for function added.
    Custom function now works as originally intended, also the progress bar now works for the function.
    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
    [ProjectThing.ino]
2023-05-20 Improved Interface layout with Bootstrap and fixed shuffle names.
    Used bootstrap to improve the layout of the interface to be more compact and readable putting text boxes next to the buttons they relate to. I also changed the names of the buttons so the user better understands what type of shuffle each one does.
    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
2023-05-20 Added Network Provisioning
    Removed hard coded WiFi connection and added network provisioning, the user can connect to http://192.168.4.1/ through their web browser after joining the access point created by the ESP32-S3 to conn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
2023-05-20 Calibrated runtime so correct number of cards are shuffled.
    The card shuffler was shuffling 5 times as many cards as inputted exactly so the changes have been made to fix this.
2023-05-20 Fixed Custom and Riffle shuffle functions on bootstrap interface.
    Bootstrap interface caused only two out of 4 buttons to work which went unnoticed originally but was discovered during testing now. The text boxes had been set up as buttons and therefore the buttons related to those text boxes were not functional. This is now fixed and the whole interface works as intended.
2023-05-20 Progress bar speed fixed
    The last commit fixed the card shuffling calibration but broke the progress bar calibration. This fixes that and also has bee tested so that other features arnt broke with this change.
2023-05-20 Added Video Demonstration of Card Shuffler
    Added a 50 second long video demonstration of the interface and card shuffler in action to demonstrate what it can do. This commit also adds a "Documentation Resources" folder for adding future asset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
2023-05-22 Added Images for Documentation
    This commit includes all current images for documentation.
2023-05-22 Added 3D print design images and software design image.
    Added 3D print design images and software design image.
2023-05-22 Added more images to documentation README
    Added more images to documentation README. Specifically the shaft images and fixed the software design image size.
2023-05-22 Shaft images moved to be side by side.
    Shaft images moved to be side by side due to height of images.
2023-05-22 Added images and assembly section to README
    Added images and assembly section for 3D print as well as hardware connections to README
2023-05-23 Finished README documentation
    Completed last parts of README documentation for the card Shuffling Device.
2023-05-23 Added 3D Print Files in Folder
    Added the STL files designed and used to 3D print the chassis.
    [big gear.stl, card holders.stl, handle for manual testing.stl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]
2023-05-26 Fixed accidental overwrite of Network Provisioning
    Network provisioning was added in a previous commit but in the final stages before submission comments and docstring were added. This commit accidentally removed network provisioning from the most recent code. This commit puts the network provisioning back into the most recent commit.
    [ProjectThing.ino]
2023-06-10 Fixed File Structure and File Naming
    Fixed File Structure and File Naming: this commit was made in preparation for code becoming open source so other people could more easily understand and navigate the project.
    [big gear.stl, card holders.stl, handle for manual testing.stl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]
